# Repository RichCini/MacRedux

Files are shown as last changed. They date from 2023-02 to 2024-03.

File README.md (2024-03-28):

# MacRedux

Reimaging of the original Macintosh 128k logic board 820-0086-C. 

## Introduction
This project is a re-implementation of a Macintosh 128k logic board. From this, I hope to
derive the 128k/512k hybrid board. Primarily, I expect these would be used to replace
an original logic board that has been damaged. There are several components that are generally 
"unobtanium" without harvesting from another board. These parts include the six PLDs (of which 
only 2 or 3 may have been decoded per some Google searching), the IWM (disk drive controller), 
the RTC chip (although a clone seems to have been made by someone), three RC dampers, and the 
external floppy connector (a custom 19-pin connector that looks like it used the DB13W3 shell
size). The DB19F was also used on the //gs, Amiga, and NeXT machines, among others. You can 
still occasionally find them on eBay. I purchased 2 just to have them for measurements.

## Project Status
The board has been fully test plotted but has not been sent to manufacturing. I was able to
purchase an original board, so most of the critical measurements have been validated. However,
there still may be minor differences between the original and this version, mostly relating to
the rear connectors, the RJ11 jack, and the pushbutton switches on the side. 

## Versions
* v1.0-001: Initial prototype based on original schematic.

## Known Bugs/Issues
* The board still contains several DRC errors, mostly due to components encroaching on
eachother ("porch violations"). There will likely be permanent encroachments given how
dense the board is in certain areas.

* Certain components (like the push buttons, keyboard connector, and audio jack) 
are being replaced with what I think are current equivalents, so further adjustments could
be needed for those so that they are positioned properly on the planar.

* As of now, the PALs have not been fully decoded. The archive includes a text
file with some notes I've collected on the topic from various places on the Net.

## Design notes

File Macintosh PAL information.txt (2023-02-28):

See actual Web file archive at
https://web.archive.org/web/20020226105207/http://www.mactech.com/articles/mactech/Vol.01/01.11/PAL/index.html)
With added information from http://retro.co.za/ccc/mac/ReverseEngineering/PALs.html

PROGRAMMABLE LOGIC IN THE MACINTOSH

512K MAC:
 
ASG  16R6 Disk speed control, sound generator.
BMU0 16R4 Ram control (read, write, DTACK)
BMU1 16L8 Address decoding
LAG  16R8 Video generator
TSG  16R6 Divide by 2, divide by 4.25.
TSM  16R4 Generates RAS and CAS for DRAM

The Macintosh uses six HAL devices, of four different types. These types are 
16L8, 16R8, 16R6, and 16R4.

The 16L8 is very similar to the example I've given, with 8 dedicated input pins, 
and 8 pins which are programmable as inputs or outputs. The part number, 16L8, 
means there are 16 possible inputs, 8 possible outputs, and the outputs are active 
low. The active low outputs can be programmed as active high using DeMorgan's Law, 
as I described above.

The 16R8 is identical to the 16L8, only there is a D-type flip-flop (register) 
at the output of each OR term. Figure 10 shows the structure of one registered 
output term. The 16R6 and 16R4 have 6 and 4 output registers respectively, with 
the remaining 2 and 4 terms direct combinatorial outputs like the 16L8.

MACINTOSH HAL FUNCTIONS

A look at the functions that the Mac's HALs perform give a good feel for the type of 
applications where programmable logic is used. There are many instances of simple 
random-logic replacement, but there are also some clever applications that demonstrate 
the versatility of these devices.

The 6 HALs in the Mac have designators silk-screened on the PC board next to them. 
I'll refer to them by those names, although I can't figure out what they stand for.

BMU1

BMU1 is a 16L8 device which performs the major address decoding functions. It has 
as inputs the higher order address lines A21, A22, and A23 from the processor, along 
with the overlay bit (for a description of the overlay bit, see the August issue). 
These bits are decoded to generate enable signals for the RAM, ROM, the IWM (disk 
controller) and the SCC serial chip.

/AS 	 I 	11	 10		GND
/IWM 	 O 	12	 9	 I 	A21
/SCCRD	 O 	13	 8	 I 	A22
/SCCEN	 O 	14	 7	 I 	A23
/VPA 	 O 	15	 6	 I 	OVERLAY
/ROM 	 O 	16	 5	 I 	L13
/RAM 	 O 	17	 4	 I 	/VCA
VC0 	 O 	18	 3	 I 	VA6
VC1 	 O 	19	 2	 I 	VA7
Vcc 		20	 1	 I 	VA8

/IWM   :=  A23 *  A22 * /A21 * /AS             ; 0xC0 0000 - 0xDF FFFF (0xDF E1FF)
/SCCRD :=  A23 * /A22 * /A21 * /AS             ; 0x80 0000 - 0x9F FFFF (0x9F FFF8)
/SCCEN :=  A23 * /A22 * /AS                    ; 0x80 0000 - 0xBF FFFF (0x9F FFF8 - RD, 0xBF FFF9 - WR)
/VPA   :=  A23 *  A22 *  A21 * /AS             ; Synchronous I/O (6800 style) 0xE0 0000 - 0xFF FFFF
/ROM   := /A23 *  A22 * /A21 * /AS             ; 0x40 0000 - 0x5F FFFF
        + /A23 * /A22 * /A21 * /AS * OVERLAY   ; 0x00 0000 - 0x1F FFFF when OVERLAY enabled
        +  A23 * /A22 * /AS                    ; 0x80 0000 - 0xBF FFFF
        +  A23 * /A21 * /AS                    ; 0x80 0000 - 0x9F FFFF and 0xC0 0000 - 0xDF FFFF
/RAM   := /A23 * /A22 * /A21 * /AS * /OVERLAY  ; 0x00 0000 - 0x1F FFFF
        + /A23 *  A22 *  A21 * /AS * OVERLAY   ; 0x60 0000 - 0x7F FFFF when OVERLAY is enabled
VC0    :=
VC1    :=

Minimized Product of Sums:
/IWM = (/AS+A21+A22'+A23');
/SCCRD = (/AS+A21+A22+A23');
/SCCEB = (/AS+A22+A23');
/VPA = (/AS+A21'+A22'+A23');
/ROM = (A22+A23')(A21+A22')(A22+OVERLAY')(A22'+A23+OVERLAY);
/RAM = (A22+A23')(A22+OVERLAY)(A21'+A22'+A23+OVERLAY');
VC0 = (L13'+/VCA+VA6')(L13+/VCA+VA7'+VA8);
VC1 = (L13'+/VCA+VA6')(L13+/VCA+VA7+VA8');

LAG

LAG is a 16R8 device which performs the majority of the video control functions. It 
has as inputs most of the video address counter outputs, which are decoded to create 
output signals which load the video shift register, provide the CRT sweep circuitry 
with horizontal and vertical syncs, increment and reset the video address counters, 
and switch the RAM address multilplexers between CPU, video, and sound addresses.

/TSEN1 	/OE 	11	10		GND
/LDPS 	 R 	12	9	 I 	VA0
/VSYNC	 R 	13	8	 I 	VA1
/HSYNC	 R 	14	7	 I 	VA2
VID/u*	 R 	15	6	 I 	TC
H4 	 R 	16	5	 I 	C1M
/DMA 	 R 	17	4	 I 	VA3
RESLYN	 R 	18	3	 I 	VC1
RESNYB	 R 	19	2	 I 	VC0
Vcc 		20	1	CLK 	C16M

A 16R8 has eight (+ a clock) inputs and eight outputs.
Clock: C16M
Inputs: VC0, VC1, VA0, VA1, VA2, VA3, TC, C1M
Outputs: /LDPS, /VSYNC, /HSYNC, VID/u*, H4, /DMA, RESLYN, RESNYB

BMU0

BMU0 is a 16R4 device which generates RAM read and write signals from the RAM enable 
output of BMU1 and the processor R/W line. It is also used as a counter to create 
two video address lines (VA12 and VA13) because the video counter is only 12 bits 
wide (VA0-VA11). In addition, it also generates DTACK, the data transfer acknowledge 
handshake signal to the processor, and synchronizes the output of the video shift 
register with the master oscillator. This is a very good example of the many 
different types of functions that can be handled with a single programmable device.

/TSEN0	/CS 	11	10		GND
/RAM_RD	 O 	12	9	 I 	R/W
/RAM_RW	 O 	13	8	 I 	L13
VA12 	 R 	14	7	 I 	L12
/VCA	 R 	15	6	 I 	VA11
/VIDOUT	 R 	16	5	 I 	VA10
VA13 	 R 	17	4	 I 	VA9
SERVID 	 O 	18	3	 I 	/ROM
/DTACK	 O 	19	2	 I 	/RAM
Vcc 		20	1	CLK 	C16M

SERVID from the dual LS166 video shifters and VIDOUT to the monitor. 

TSM

TSM is a 16R4 device whose major function is control of the dynamic RAM. For inputs, 
it has the decoded RAM enable signal, along with the address and data strobes from 
the processor which signify whether the data transfer will be low byte, hi byte, 
or word. From these the RAS and CAS strobes are generated, and the row/column address 
multiplexer is controlled. Until there were PALs, this type of dynamic RAM control 
function required either about 10-20 discrete TTL packages, or a 40 pin LSI dynamic 
RAM controller which usually didn't do what you wanted anyway.

/TSEN0	/CS 	11	10		GND
/CAS0 	 O 	12	9	 I 	/LDS
/CAS1 	 O 	13	8	 I 	/UDS
/RAS 	 R 	14	7	 I 	/AS
TC 	 R 	15	6	 I 	/ROM
C1M 	 R 	16	5	 I 	/RAM
C4M 	 R 	17	4	 I 	VID/u*
C2M 	 O 	18	3	 I 	C8M
/DTACK	 O 	19	2	 I 	C16M
Vcc 		20	1	CLK 	C16M

PAL16R8	 PAL DESIGN SPECIFICATIONS

16MBUF C16M 8M MU RAMEN ROMEN AS UDS LDS GND 
TSEN CAS0 CAS1 RAS TC 1M 4M 2M DTACK VCC

RAS is the DRAM Row Address Strobe.

RAS: =       /4M *             /RAS
     +  8M *  4M *             /RAS + 
     + /8M *  4M *       /2M * /RAS
     +  8M * /4M *  1M *        RAS
     +  8M * /4M * /1M *  2M *  RAS
     + /8M *  4M * /1M *        RAS *  LDS
     + /8M *  4M * /1M *        RAS *  UDS
     + /8M *  4M * /1M *        RAS * /LDS * /UDS * /CAS0
     + 

TC goes to the LAG and to the video counter (U1F)

TC:= 8M + /4M + 2M +  /1M + RAS

1M: =      /8M *  4M * /2M * 1M * /RAS + 
     /1M *  8M * /4M * /RAS + 
     /1M * /8M *  4M * 2M * /RAS + 
     /1M *              RAS + 
     /1M * /8M * /4M * /RAS + 
     /1M * 8M *   4M * /RAS

4M: =                    1M *  RAS + 
       8M *  4M *  2M * /1M *  RAS + 
      /8M * /4M *       /1M *  RAS + 
       8M * /4M *  2M * /1M *  RAS + 
      /8M *  4M * /2M *       /RAS + 
there may be a line missing here..... 

2M: = /C16M *       /8M * /4M * /RAS
    +         /2M + /8M + /4M 
    +         /2M + /1M + * /TC
    +  C16M * /2M
    + /C16M * /8M * /4M * /1M * RAS * /ROMEN * /RAMEN * /AS
    + /2M * 4M
    + /2M * 8M * /4M *1M * MU

DTACK := /C16M * /8M * /4M *        /RAS * /AS * /ROMEN *  RAMEN
      +  /C16M * /8M * /4M * /1M  * /RAS * /AS * /RAMEN *  ROMEN
      +  /C16M * /8M * /4M *  1M  * /RAS * /AS * /RAMEN *  ROMEN * /MU
      +  /C16M * /8M *  4M * /1M  *  RAS * /AS * /RAMEN * /ROMEN
      +  /DTACK * /UDS
      +  /DATACK * /LDS
      +  /DATACK * /RAS

This is probably not right for the Mac Plus...

CAS0: =  4M * /2M * /RAS * /DTACK * /RAMEN * ROMEN * /LDS * MU
      +  4M * /2M * 1M * /RAS * MU
      + /CAS0 
      + /RAS
      +  8M + 4M + /2M * /1M * RAS * /DTACK
      + /CAS0 * /2M + /1M

CAS1: = 4M * /2M * /RAS * /DTACK * /RAMEN * ROMEN * /UDS * MU
      + 4M * /2M * 1M * /RAS * MU
      + /CAS1 + /RAS 

ASG

ASG is a 16R6 device which illustrates why PALs can be so valuable. It's primary 
purpose is to take the 6-bit disk speed value which is fetched at the end of every
horizontal retrace period and convert it to a pulse-width modulated signal. Basically, 
it's a 6-bit counter. This leaves a couple of inputs and an output available, which 
are used to control the loading of the sound generator pulse-width modulator, which 
is a counter made up of TTL devices. If a discrete counter had been used for the 
disk PWM, another chip would have been required for the sound PWM load function. 
Using a PAL for a simple counter function in this instance saved a chip in the design.

As usual, Burrell's new design was very clever. The Macintosh was already continuously 
fetching data from memory to drive the video display, interleaving memory bandwidth 
between the display and processor in a similar fashion to the Apple II. But every 
44 microseconds, there was a "horizontal blanking interval" where no video data was 
needed, so Burrell used that time to fetch data for the sound. That gave us a sample 
rate of 22kHz, which would allow us to do frequencies up to 11kHz, which isn't too bad. 

/TSEN2	/OE 	11	 10		GND
/DMALD	 O 	12	 9	 I 	TC
PWM 	 R 	13	 8	 I 	/DMA
N/C 	 R 	14	 7	 I 	RDQ5
N/C 	 R 	15	 6	 I 	RDQ4
N/C 	 R 	16	 5	 I 	RDQ3
N/C 	 R 	17	 4	 I 	RDQ2
N/C 	 R 	18	 3	 I 	RDQ1
N/C 	 O 	19	 2	 I 	RDQ0
Vcc 		20	 1	CLK 	C16MF

TSG

This one is my favorite. The TSG is a 16R6 device which illustrates the power of 
programmable logic. It serves a couple of mundane functions concerning interrupts 
and the keyboard clock, but by far it's most interesting job is as a clock generator 
for the SCC serial chip.

The master oscillator frequency in the Macintosh is 15.667 MHz. This is divided by 2 
in the TSG to get the 7.834 MHz processor clock. In order for the SCC to be able to 
operate at a baud rate of 230.4 KBaud, which is what AppleTalk requires, it needs an 
input clock frequency of 3.686 MHz.

If you pull down your calculator desk accessory, you'll find that 15.667 ÷ 3.686 = 4.25. 
This means that the TSG needs to divide the 15.667 MHz master oscillator by 4.25 in 
order to get a 3.686 MHz clock. How is this done, since 4.25 is not even an integer, 
let alone a binary number?

Let's call the 15.667 MHz clock the MO_clk and the 3.686 MHz clock the SCC_clk. For 
every 17 MO_clk periods there are 4 SCC_clk periods (17 ÷ 4 = 4.25). The way the TSG 
generates the SCC_clk is count to 4 three times and then count to 5 once 
(4 + 4 + 4 + 5 = 17). See Figure 11 for a graphical description. Try that using a 
single TTL counter chip!

TSEN2 	/OE 	11	 10		GND
D0 	 O 	12	 9	 I 	/VIAIRQ
N/C 	 R 	13	 8	 I 	/IPL1
C3.7MF 	 R 	14	 7	 I 	KBD.ACLK
N/C 	 R 	15	 6	 I 	Eu
N/C 	 R 	16	 5	 I 	4M
KBD.SCLK R 	17	 4	 I 	TC
C8M 	 R 	18	 3	 I 	A19
/IPL0 	 O 	19	 2	 I 	/VPA
Vcc 		20	 1	CLK 	C16M

C8M :=

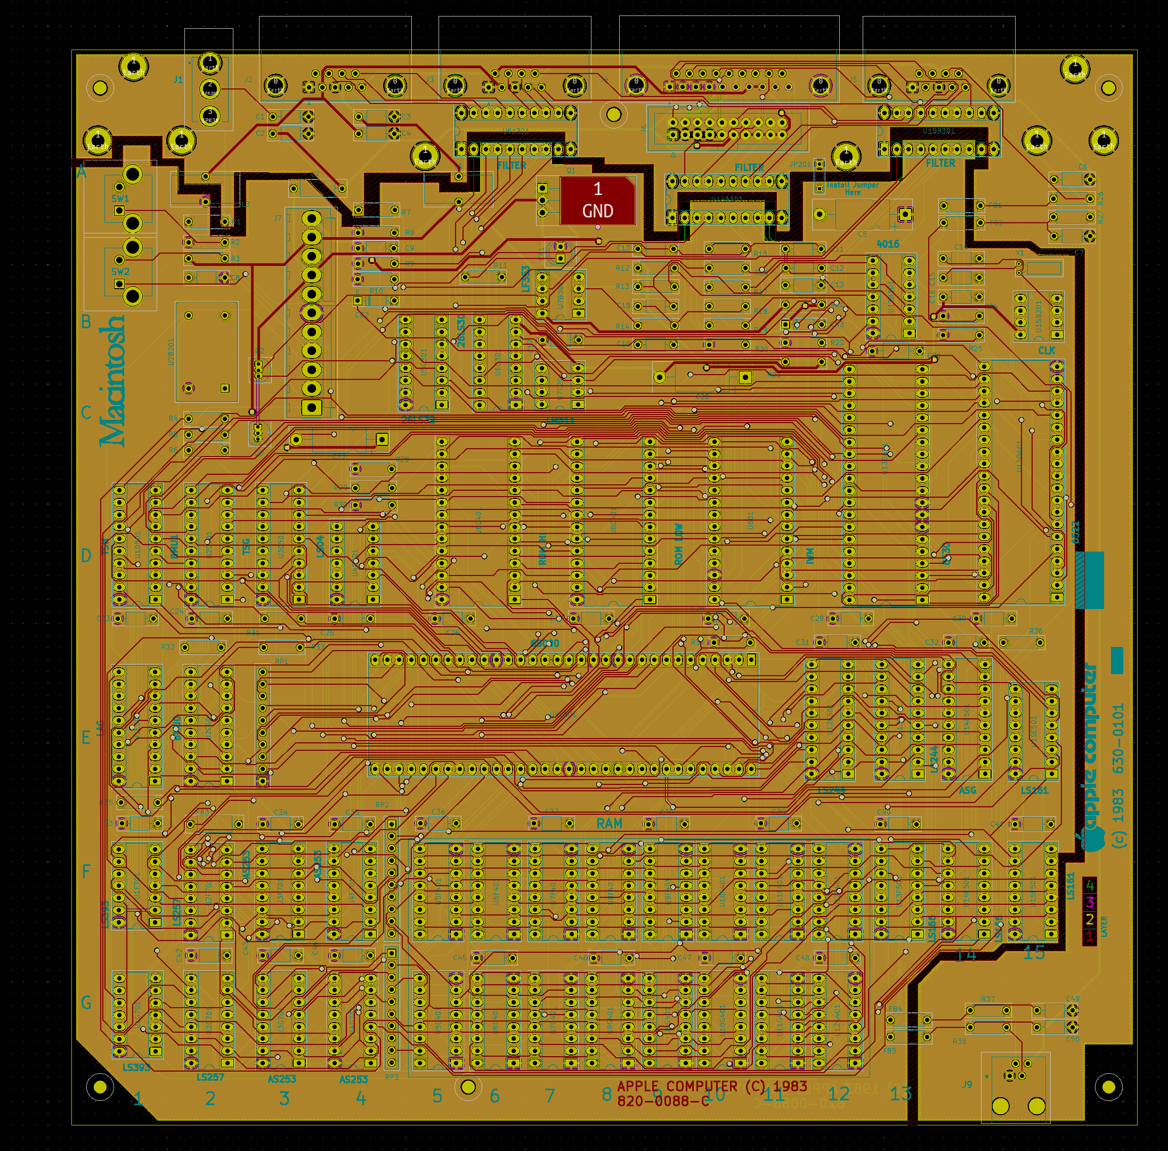
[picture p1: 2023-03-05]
Screen Shot 2023-02-06 at 2.04.48 PM.png

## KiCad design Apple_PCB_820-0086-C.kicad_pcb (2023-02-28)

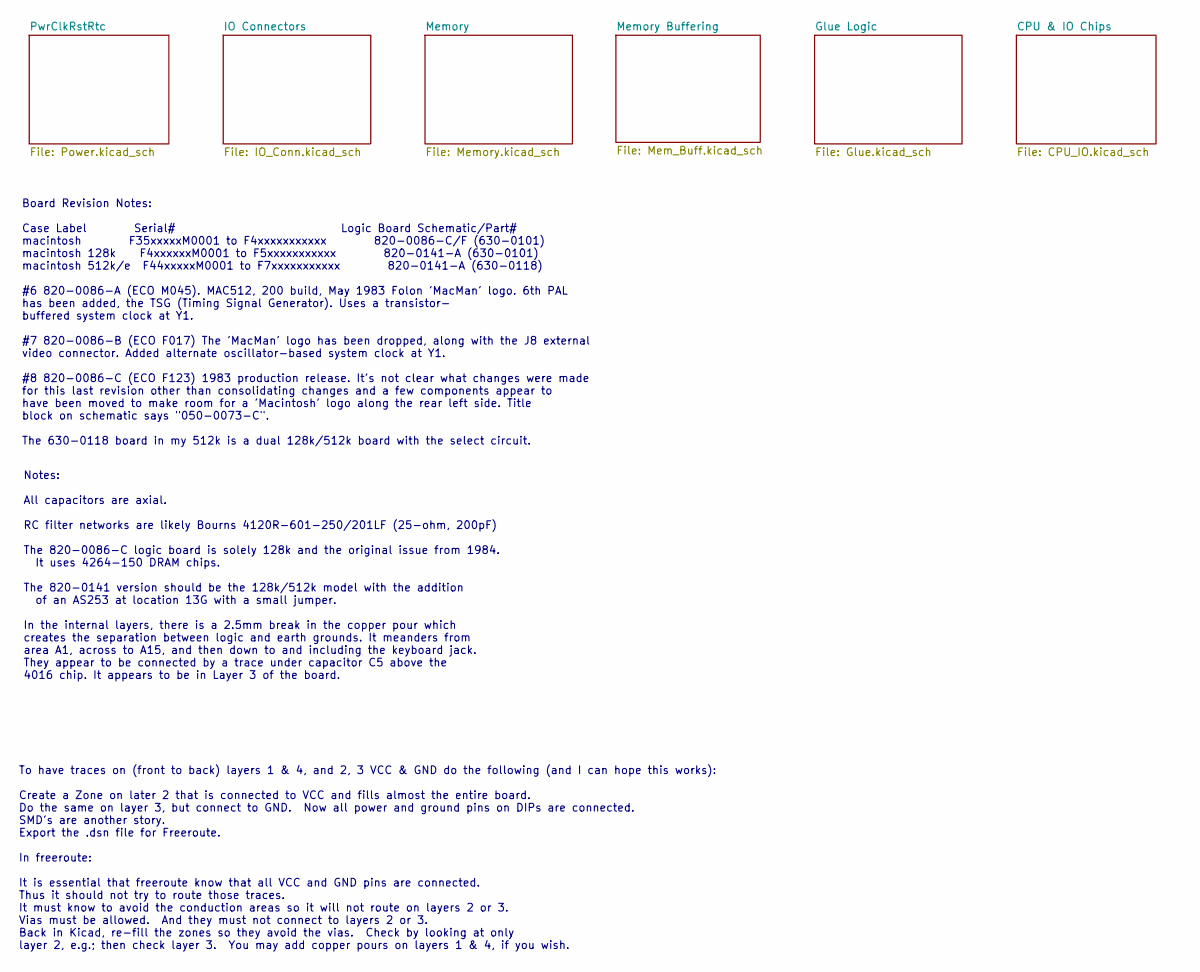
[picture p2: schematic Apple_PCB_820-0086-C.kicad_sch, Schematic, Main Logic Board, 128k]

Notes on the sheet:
Board Revision Notes: Case Label Serial# Logic Board Schematic/Part# macintosh F35xxxxxM0001 to F4xxxxxxxxxxx 820-0086-C/F (630-0101) macintosh 128k F4xxxxxxM0001 to F5xxxxxxxxxxx 820-0141-A (630-0101) macintosh 512k/e F44xxxxxM0001 to F7xxxxxxxxxxx 820-0141-A (630-0118) #6 820-0086-A (ECO M045). M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
To have traces on (front to back) layers 1 & 4, and 2, 3 VCC & GND do the following (and I can hope this works): Create a Zone on later 2 that is connected to VCC and fills almost the entire board. Do the same on layer 3, but connect to GND. Now all power and ground pins on DIPs are connected. SMD'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
Notes: All capacitors are axial. RC filter networks are likely Bourns 4120R-601-250/201LF (25-ohm, 200pF) The 820-0086-C logic board is solely 128k and the original issue from 1984. It uses 4264-150 DRAM chips. The 820-0141 version should be the 128k/512k model with the addition of an AS253 at loca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

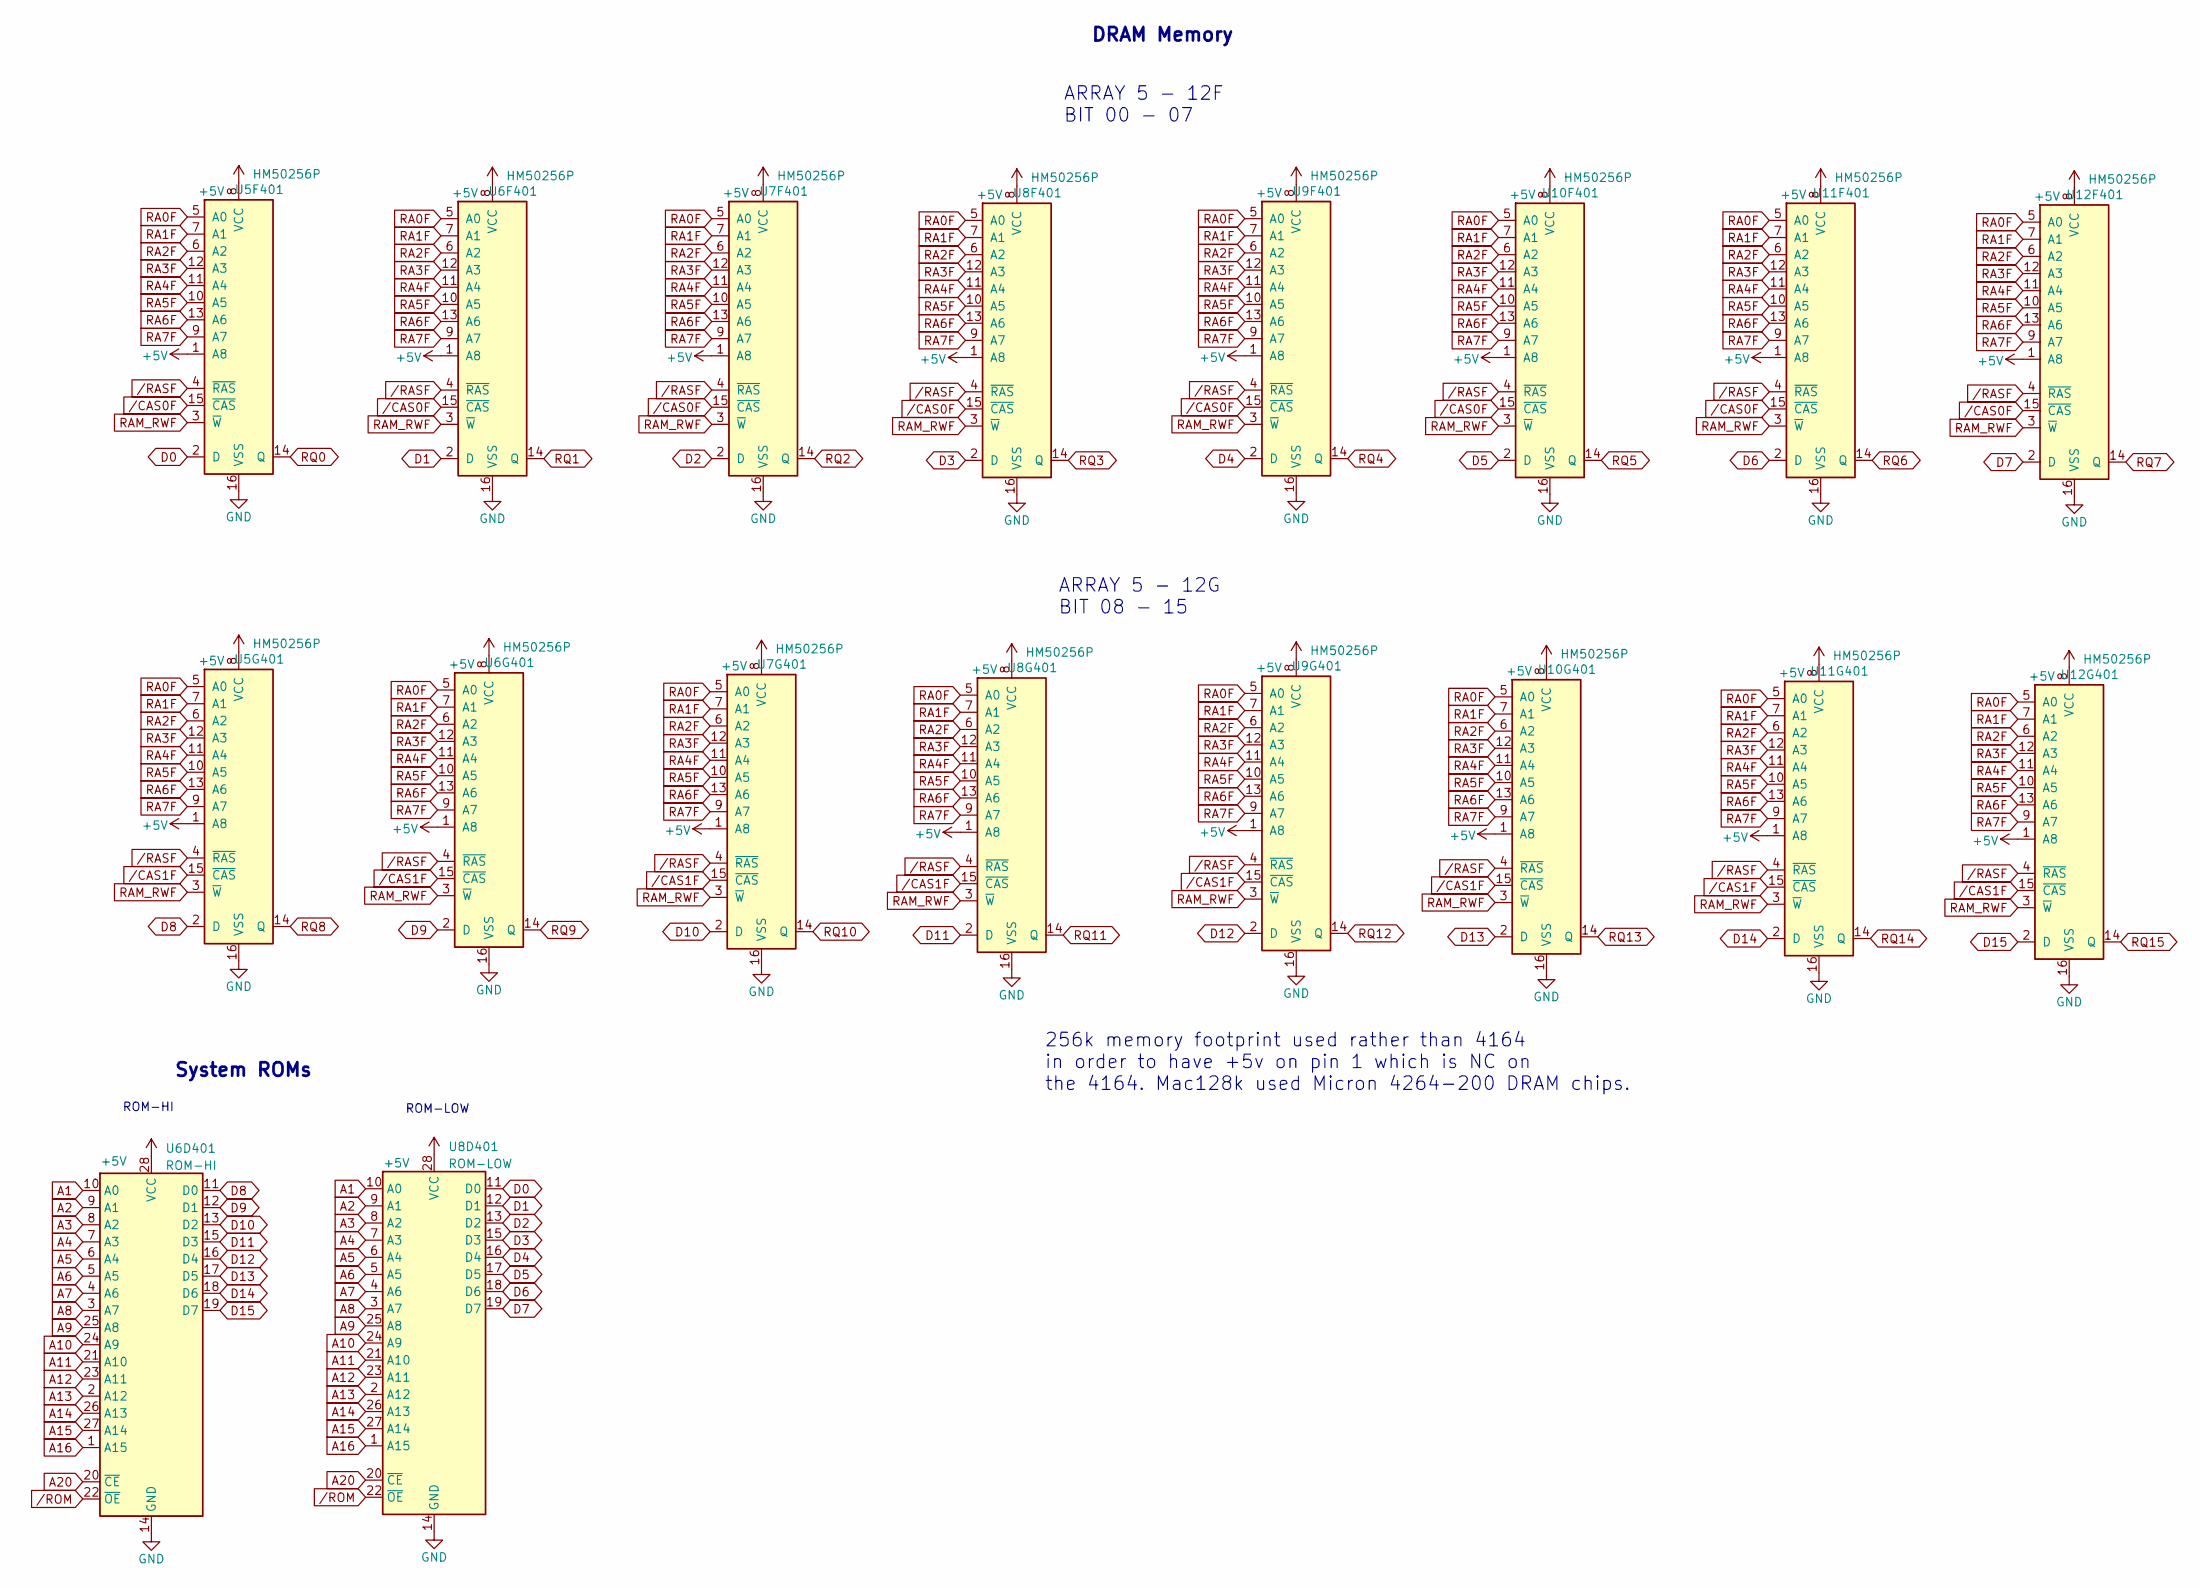
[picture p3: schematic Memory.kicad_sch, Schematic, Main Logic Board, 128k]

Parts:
U5F401, U5G401, U6F401, U6G401, U7F401, U7G401, U8F401, U8G401, U9F401, U9G401, U10F401, U10G401, U11F401, U11G401, U12F401, U12G401: HM50256P; DIP-16_W7.62mm_Socket_LongPads
U6D401: ROM-HI; DIP-28_W15.24mm_LongPads
U8D401: ROM-LOW; DIP-28_W15.24mm_LongPads

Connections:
+5V: U5F401.1 (A8), U5F401.8 (VCC), U5G401.1 (A8), U5G401.8 (VCC), U6D401.28 (VCC), U6F401.1 (A8), U6F401.8 (VCC), U6G401.1 (A8), U6G401.8 (VCC), U7F401.1 (A8), U7F401.8 (VCC), U7G401.1 (A8), U7G401.8 (VCC), U8D401.28 (VCC), U8F401.1 (A8), U8F401.8 (VCC), U8G401.1 (A8), U8G401.8 (VCC), U9F401.1 (A8), U9F401.8 (VCC), U9G401.1 (A8), U9G401.8 (VCC), U10F401.1 (A8), U10F401.8 (VCC), U10G401.1 (A8), U10G401.8 (VCC), U11F401.1 (A8), U11F401.8 (VCC), U11G401.1 (A8), U11G401.8 (VCC), U12F401.1 (A8), U12F401.8 (VCC), U12G401.1 (A8), U12G401.8 (VCC); also elsewhere on the board
A1: U6D401.10 (A0), U8D401.10 (A0); also elsewhere on the board
A2: U6D401.9 (A1), U8D401.9 (A1); also elsewhere on the board
A3: U6D401.8 (A2), U8D401.8 (A2); also elsewhere on the board
A4: U6D401.7 (A3), U8D401.7 (A3); also elsewhere on the board
A5: U6D401.6 (A4), U8D401.6 (A4); also elsewhere on the board
A6: U6D401.5 (A5), U8D401.5 (A5); also elsewhere on the board
A7: U6D401.4 (A6), U8D401.4 (A6); also elsewhere on the board
A8: U6D401.3 (A7), U8D401.3 (A7); also elsewhere on the board
A9: U6D401.25 (A8), U8D401.25 (A8); also elsewhere on the board
A10: U6D401.24 (A9), U8D401.24 (A9); also elsewhere on the board
A11: U6D401.21 (A10), U8D401.21 (A10); also elsewhere on the board
A12: U6D401.23 (A11), U8D401.23 (A11); also elsewhere on the board
A13: U6D401.2 (A12), U8D401.2 (A12); also elsewhere on the board
A14: U6D401.26 (A13), U8D401.26 (A13); also elsewhere on the board
A15: U6D401.27 (A14), U8D401.27 (A14); also elsewhere on the board
A16: U6D401.1 (A15), U8D401.1 (A15); also elsewhere on the board
A20: U6D401.20 (~CE), U8D401.20 (~CE); also elsewhere on the board
D0: U5F401.2 (D), U8D401.11 (D0); also elsewhere on the board
D1: U6F401.2 (D), U8D401.12 (D1); also elsewhere on the board
D2: U7F401.2 (D), U8D401.13 (D2); also elsewhere on the board
D3: U8D401.15 (D3), U8F401.2 (D); also elsewhere on the board
D4: U8D401.16 (D4), U9F401.2 (D); also elsewhere on the board
D5: U8D401.17 (D5), U10F401.2 (D); also elsewhere on the board
D6: U8D401.18 (D6), U11F401.2 (D); also elsewhere on the board
D7: U8D401.19 (D7), U12F401.2 (D); also elsewhere on the board
D8: U5G401.2 (D), U6D401.11 (D0); also elsewhere on the board
D9: U6D401.12 (D1), U6G401.2 (D); also elsewhere on the board
D10: U6D401.13 (D2), U7G401.2 (D); also elsewhere on the board
D11: U6D401.15 (D3), U8G401.2 (D); also elsewhere on the board
D12: U6D401.16 (D4), U9G401.2 (D); also elsewhere on the board
D13: U6D401.17 (D5), U10G401.2 (D); also elsewhere on the board
D14: U6D401.18 (D6), U11G401.2 (D); also elsewhere on the board
D15: U6D401.19 (D7), U12G401.2 (D); also elsewhere on the board
GND: U5F401.16 (VSS), U5G401.16 (VSS), U6D401.14 (GND), U6F401.16 (VSS), U6G401.16 (VSS), U7F401.16 (VSS), U7G401.16 (VSS), U8D401.14 (GND), U8F401.16 (VSS), U8G401.16 (VSS), U9F401.16 (VSS), U9G401.16 (VSS), U10F401.16 (VSS), U10G401.16 (VSS), U11F401.16 (VSS), U11G401.16 (VSS), U12F401.16 (VSS), U12G401.16 (VSS); also elsewhere on the board
RA0F: U5F401.5 (A0), U5G401.5 (A0), U6F401.5 (A0), U6G401.5 (A0), U7F401.5 (A0), U7G401.5 (A0), U8F401.5 (A0), U8G401.5 (A0), U9F401.5 (A0), U9G401.5 (A0), U10F401.5 (A0), U10G401.5 (A0), U11F401.5 (A0), U11G401.5 (A0), U12F401.5 (A0), U12G401.5 (A0); also elsewhere on the board
RA1F: U5F401.7 (A1), U5G401.7 (A1), U6F401.7 (A1), U6G401.7 (A1), U7F401.7 (A1), U7G401.7 (A1), U8F401.7 (A1), U8G401.7 (A1), U9F401.7 (A1), U9G401.7 (A1), U10F401.7 (A1), U10G401.7 (A1), U11F401.7 (A1), U11G401.7 (A1), U12F401.7 (A1), U12G401.7 (A1); also elsewhere on the board
RA2F: U5F401.6 (A2), U5G401.6 (A2), U6F401.6 (A2), U6G401.6 (A2), U7F401.6 (A2), U7G401.6 (A2), U8F401.6 (A2), U8G401.6 (A2), U9F401.6 (A2), U9G401.6 (A2), U10F401.6 (A2), U10G401.6 (A2), U11F401.6 (A2), U11G401.6 (A2), U12F401.6 (A2), U12G401.6 (A2); also elsewhere on the board
RA3F: U5F401.12 (A3), U5G401.12 (A3), U6F401.12 (A3), U6G401.12 (A3), U7F401.12 (A3), U7G401.12 (A3), U8F401.12 (A3), U8G401.12 (A3), U9F401.12 (A3), U9G401.12 (A3), U10F401.12 (A3), U10G401.12 (A3), U11F401.12 (A3), U11G401.12 (A3), U12F401.12 (A3), U12G401.12 (A3); also elsewhere on the board
RA4F: U5F401.11 (A4), U5G401.11 (A4), U6F401.11 (A4), U6G401.11 (A4), U7F401.11 (A4), U7G401.11 (A4), U8F401.11 (A4), U8G401.11 (A4), U9F401.11 (A4), U9G401.11 (A4), U10F401.11 (A4), U10G401.11 (A4), U11F401.11 (A4), U11G401.11 (A4), U12F401.11 (A4), U12G401.11 (A4); also elsewhere on the board
RA5F: U5F401.10 (A5), U5G401.10 (A5), U6F401.10 (A5), U6G401.10 (A5), U7F401.10 (A5), U7G401.10 (A5), U8F401.10 (A5), U8G401.10 (A5), U9F401.10 (A5), U9G401.10 (A5), U10F401.10 (A5), U10G401.10 (A5), U11F401.10 (A5), U11G401.10 (A5), U12F401.10 (A5), U12G401.10 (A5); also elsewhere on the board
RA6F: U5F401.13 (A6), U5G401.13 (A6), U6F401.13 (A6), U6G401.13 (A6), U7F401.13 (A6), U7G401.13 (A6), U8F401.13 (A6), U8G401.13 (A6), U9F401.13 (A6), U9G401.13 (A6), U10F401.13 (A6), U10G401.13 (A6), U11F401.13 (A6), U11G401.13 (A6), U12F401.13 (A6), U12G401.13 (A6); also elsewhere on the board
RA7F: U5F401.9 (A7), U5G401.9 (A7), U6F401.9 (A7), U6G401.9 (A7), U7F401.9 (A7), U7G401.9 (A7), U8F401.9 (A7), U8G401.9 (A7), U9F401.9 (A7), U9G401.9 (A7), U10F401.9 (A7), U10G401.9 (A7), U11F401.9 (A7), U11G401.9 (A7), U12F401.9 (A7), U12G401.9 (A7); also elsewhere on the board
RAM_RWF: U5F401.3 (~W), U5G401.3 (~W), U6F401.3 (~W), U6G401.3 (~W), U7F401.3 (~W), U7G401.3 (~W), U8F401.3 (~W), U8G401.3 (~W), U9F401.3 (~W), U9G401.3 (~W), U10F401.3 (~W), U10G401.3 (~W), U11F401.3 (~W), U11G401.3 (~W), U12F401.3 (~W), U12G401.3 (~W); also elsewhere on the board
RQ0: U5F401.14 (Q); also elsewhere on the board
RQ1: U6F401.14 (Q); also elsewhere on the board
RQ2: U7F401.14 (Q); also elsewhere on the board
RQ3: U8F401.14 (Q); also elsewhere on the board
RQ4: U9F401.14 (Q); also elsewhere on the board
RQ5: U10F401.14 (Q); also elsewhere on the board
RQ6: U11F401.14 (Q); also elsewhere on the board
RQ7: U12F401.14 (Q); also elsewhere on the board
RQ8: U5G401.14 (Q); also elsewhere on the board
RQ9: U6G401.14 (Q); also elsewhere on the board
RQ10: U7G401.14 (Q); also elsewhere on the board
RQ11: U8G401.14 (Q); also elsewhere on the board
RQ12: U9G401.14 (Q); also elsewhere on the board
RQ13: U10G401.14 (Q); also elsewhere on the board
RQ14: U11G401.14 (Q); also elsewhere on the board
RQ15: U12G401.14 (Q); also elsewhere on the board
/CAS0F: U5F401.15 (~CAS), U6F401.15 (~CAS), U7F401.15 (~CAS), U8F401.15 (~CAS), U9F401.15 (~CAS), U10F401.15 (~CAS), U11F401.15 (~CAS), U12F401.15 (~CAS); also elsewhere on the board
/CAS1F: U5G401.15 (~CAS), U6G401.15 (~CAS), U7G401.15 (~CAS), U8G401.15 (~CAS), U9G401.15 (~CAS), U10G401.15 (~CAS), U11G401.15 (~CAS), U12G401.15 (~CAS); also elsewhere on the board
/RASF: U5F401.4 (~RAS), U5G401.4 (~RAS), U6F401.4 (~RAS), U6G401.4 (~RAS), U7F401.4 (~RAS), U7G401.4 (~RAS), U8F401.4 (~RAS), U8G401.4 (~RAS), U9F401.4 (~RAS), U9G401.4 (~RAS), U10F401.4 (~RAS), U10G401.4 (~RAS), U11F401.4 (~RAS), U11G401.4 (~RAS), U12F401.4 (~RAS), U12G401.4 (~RAS); also elsewhere on the board
/ROM: U6D401.22 (~OE), U8D401.22 (~OE); also elsewhere on the board

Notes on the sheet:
ARRAY 5 - 12F BIT 00 - 07
ROM-LOW
DRAM Memory
System ROMs
ARRAY 5 - 12G BIT 08 - 15
ROM-HI
256k memory footprint used rather than 4164 in order to have +5v on pin 1 which is NC on the 4164. Mac128k used Micron 4264-200 DRAM chips.

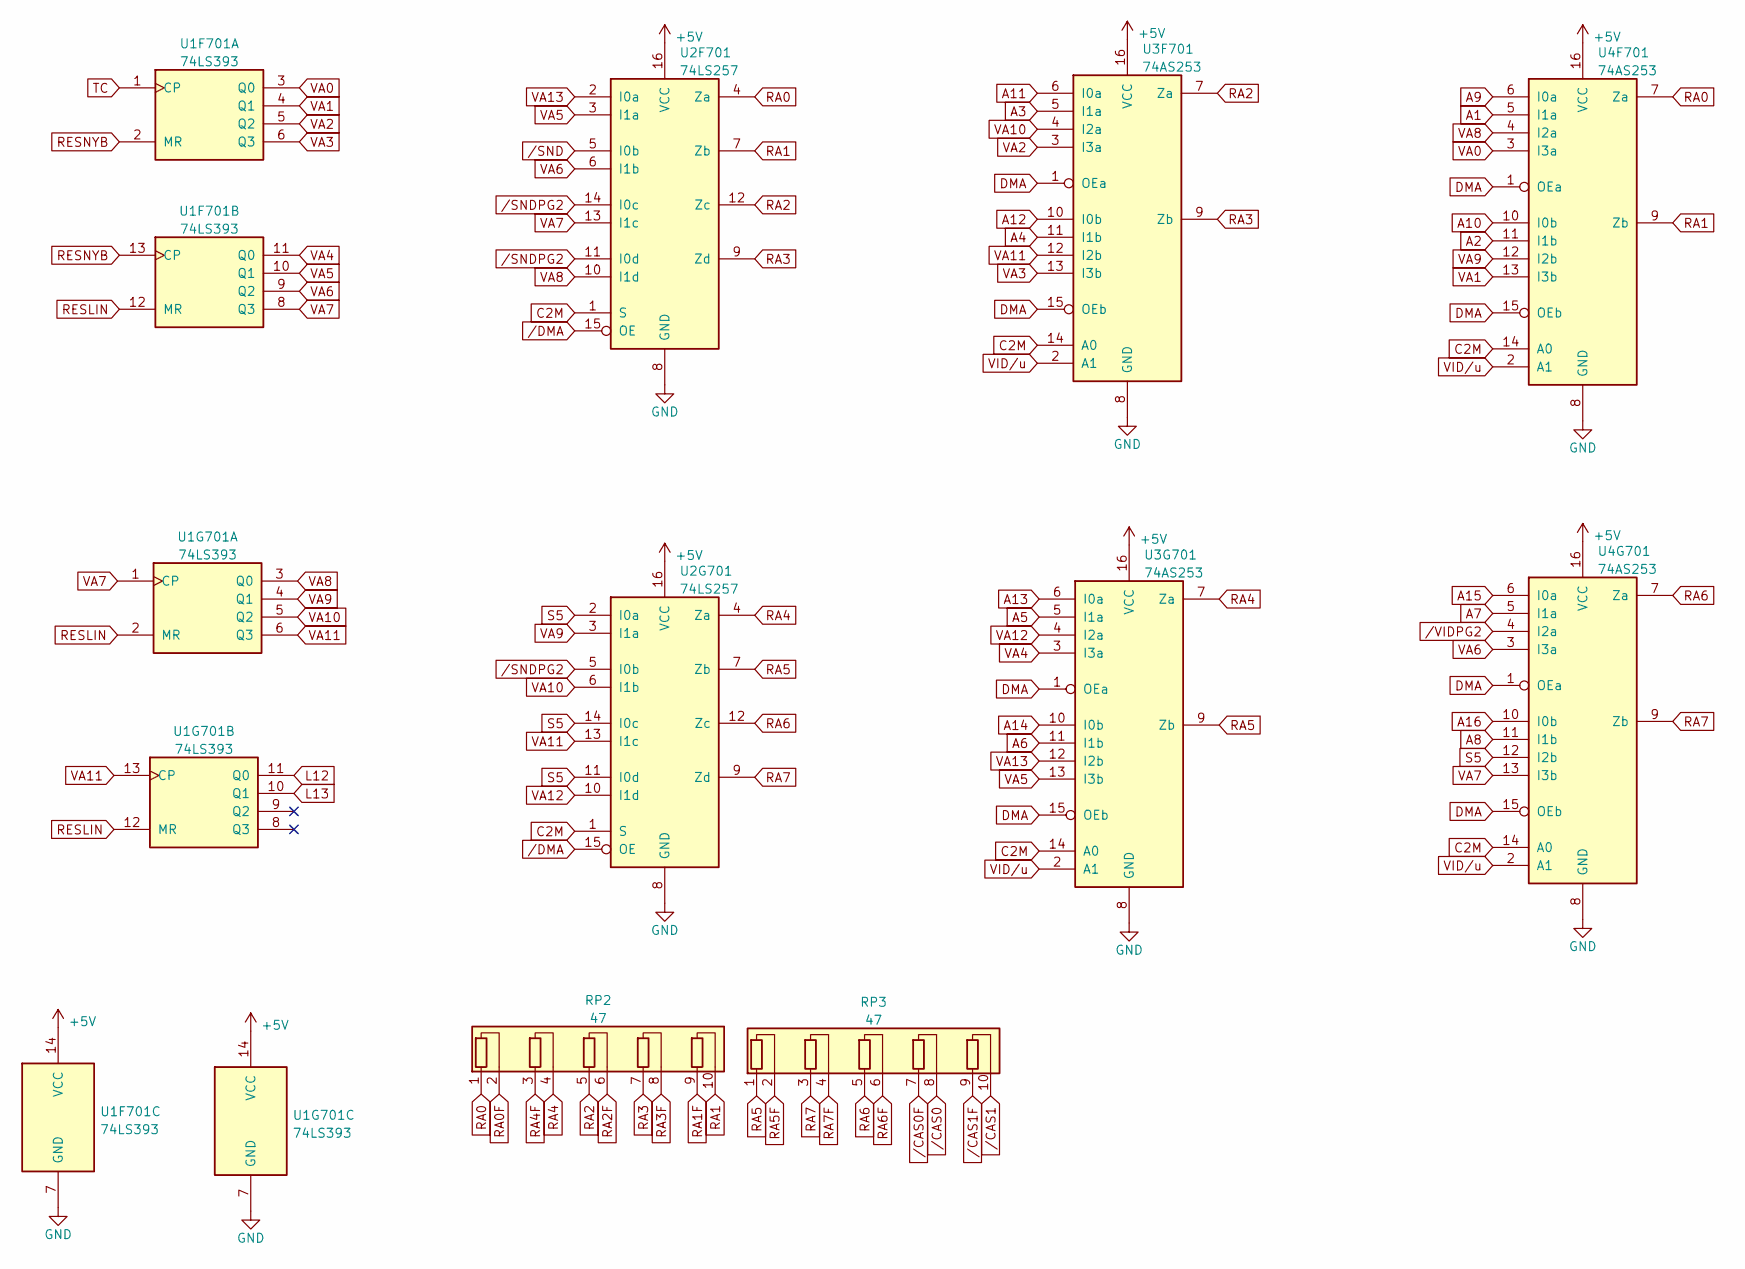
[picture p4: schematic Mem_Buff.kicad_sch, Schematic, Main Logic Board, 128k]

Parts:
RP2, RP3: 47; R_Array_SIP10
U1F701, U1G701: 74LS393; DIP-14_W7.62mm_Socket_LongPads
U2F701, U2G701: 74LS257; DIP-16_W7.62mm_Socket_LongPads
U3F701, U3G701, U4F701, U4G701: 74AS253; DIP-16_W7.62mm_Socket_LongPads

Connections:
+5V: U1F701.14 (VCC), U1G701.14 (VCC), U2F701.16 (VCC), U2G701.16 (VCC), U3F701.16 (VCC), U3G701.16 (VCC), U4F701.16 (VCC), U4G701.16 (VCC); also elsewhere on the board
A1: U4F701.5 (I1a); also elsewhere on the board
A2: U4F701.11 (I1b); also elsewhere on the board
A3: U3F701.5 (I1a); also elsewhere on the board
A4: U3F701.11 (I1b); also elsewhere on the board
A5: U3G701.5 (I1a); also elsewhere on the board
A6: U3G701.11 (I1b); also elsewhere on the board
A7: U4G701.5 (I1a); also elsewhere on the board
A8: U4G701.11 (I1b); also elsewhere on the board
A9: U4F701.6 (I0a); also elsewhere on the board
A10: U4F701.10 (I0b); also elsewhere on the board
A11: U3F701.6 (I0a); also elsewhere on the board
A12: U3F701.10 (I0b); also elsewhere on the board
A13: U3G701.6 (I0a); also elsewhere on the board
A14: U3G701.10 (I0b); also elsewhere on the board
A15: U4G701.6 (I0a); also elsewhere on the board
A16: U4G701.10 (I0b); also elsewhere on the board
C2M: U2F701.1 (S), U2G701.1 (S), U3F701.14 (A0), U3G701.14 (A0), U4F701.14 (A0), U4G701.14 (A0); also elsewhere on the board
DMA: U3F701.1 (OEa), U3F701.15 (OEb), U3G701.1 (OEa), U3G701.15 (OEb), U4F701.1 (OEa), U4F701.15 (OEb), U4G701.1 (OEa), U4G701.15 (OEb); also elsewhere on the board
GND: U1F701.7 (GND), U1G701.7 (GND), U2F701.8 (GND), U2G701.8 (GND), U3F701.8 (GND), U3G701.8 (GND), U4F701.8 (GND), U4G701.8 (GND); also elsewhere on the board
L12: U1G701.11 (Q0); also elsewhere on the board
L13: U1G701.10 (Q1); also elsewhere on the board
RA0: RP2.1 (R1.1), U2F701.4 (Za), U4F701.7 (Za)
RA0F: RP2.2 (R1.2); also elsewhere on the board
RA1: RP2.10 (R5.2), U2F701.7 (Zb), U4F701.9 (Zb)
RA1F: RP2.9 (R5.1); also elsewhere on the board
RA2: RP2.5 (R3.1), U2F701.12 (Zc), U3F701.7 (Za)
RA2F: RP2.6 (R3.2); also elsewhere on the board
RA3: RP2.7 (R4.1), U2F701.9 (Zd), U3F701.9 (Zb)
RA3F: RP2.8 (R4.2); also elsewhere on the board
RA4: RP2.4 (R2.2), U2G701.4 (Za), U3G701.7 (Za)
RA4F: RP2.3 (R2.1); also elsewhere on the board
RA5: RP3.1 (R1.1), U2G701.7 (Zb), U3G701.9 (Zb)
RA5F: RP3.2 (R1.2); also elsewhere on the board
RA6: RP3.5 (R3.1), U2G701.12 (Zc), U4G701.7 (Za)
RA6F: RP3.6 (R3.2); also elsewhere on the board
RA7: RP3.3 (R2.1), U2G701.9 (Zd), U4G701.9 (Zb)
RA7F: RP3.4 (R2.2); also elsewhere on the board
RESLIN: U1F701.12 (MR), U1G701.2 (MR), U1G701.12 (MR); also elsewhere on the board
RESNYB: U1F701.2 (MR), U1F701.13 (CP); also elsewhere on the board
S5: U2G701.2 (I0a), U2G701.11 (I0d), U2G701.14 (I0c), U4G701.12 (I2b); also elsewhere on the board
TC: U1F701.1 (CP); also elsewhere on the board
VA0: U1F701.3 (Q0), U4F701.3 (I3a); also elsewhere on the board
VA1: U1F701.4 (Q1), U4F701.13 (I3b); also elsewhere on the board
VA2: U1F701.5 (Q2), U3F701.3 (I3a); also elsewhere on the board
VA3: U1F701.6 (Q3), U3F701.13 (I3b); also elsewhere on the board
VA4: U1F701.11 (Q0), U3G701.3 (I3a)
VA5: U1F701.10 (Q1), U2F701.3 (I1a), U3G701.13 (I3b)
VA6: U1F701.9 (Q2), U2F701.6 (I1b), U4G701.3 (I3a); also elsewhere on the board
VA7: U1F701.8 (Q3), U1G701.1 (CP), U2F701.13 (I1c), U4G701.13 (I3b); also elsewhere on the board
VA8: U1G701.3 (Q0), U2F701.10 (I1d), U4F701.4 (I2a); also elsewhere on the board
VA9: U1G701.4 (Q1), U2G701.3 (I1a), U4F701.12 (I2b); also elsewhere on the board
VA10: U1G701.5 (Q2), U2G701.6 (I1b), U3F701.4 (I2a); also elsewhere on the board
VA11: U1G701.6 (Q3), U1G701.13 (CP), U2G701.13 (I1c), U3F701.12 (I2b); also elsewhere on the board
VA12: U2G701.10 (I1d), U3G701.4 (I2a); also elsewhere on the board
VA13: U2F701.2 (I0a), U3G701.12 (I2b); also elsewhere on the board
VID/u: U3F701.2 (A1), U3G701.2 (A1), U4F701.2 (A1), U4G701.2 (A1); also elsewhere on the board
/CAS0: RP3.8 (R4.2); also elsewhere on the board
/CAS0F: RP3.7 (R4.1); also elsewhere on the board
/CAS1: RP3.10 (R5.2); also elsewhere on the board
/CAS1F: RP3.9 (R5.1); also elsewhere on the board
/DMA: U2F701.15 (OE), U2G701.15 (OE); also elsewhere on the board
/SND: U2F701.5 (I0b); also elsewhere on the board
/SNDPG2: U2F701.11 (I0d), U2F701.14 (I0c), U2G701.5 (I0b); also elsewhere on the board
/VIDPG2: U4G701.4 (I2a); also elsewhere on the board

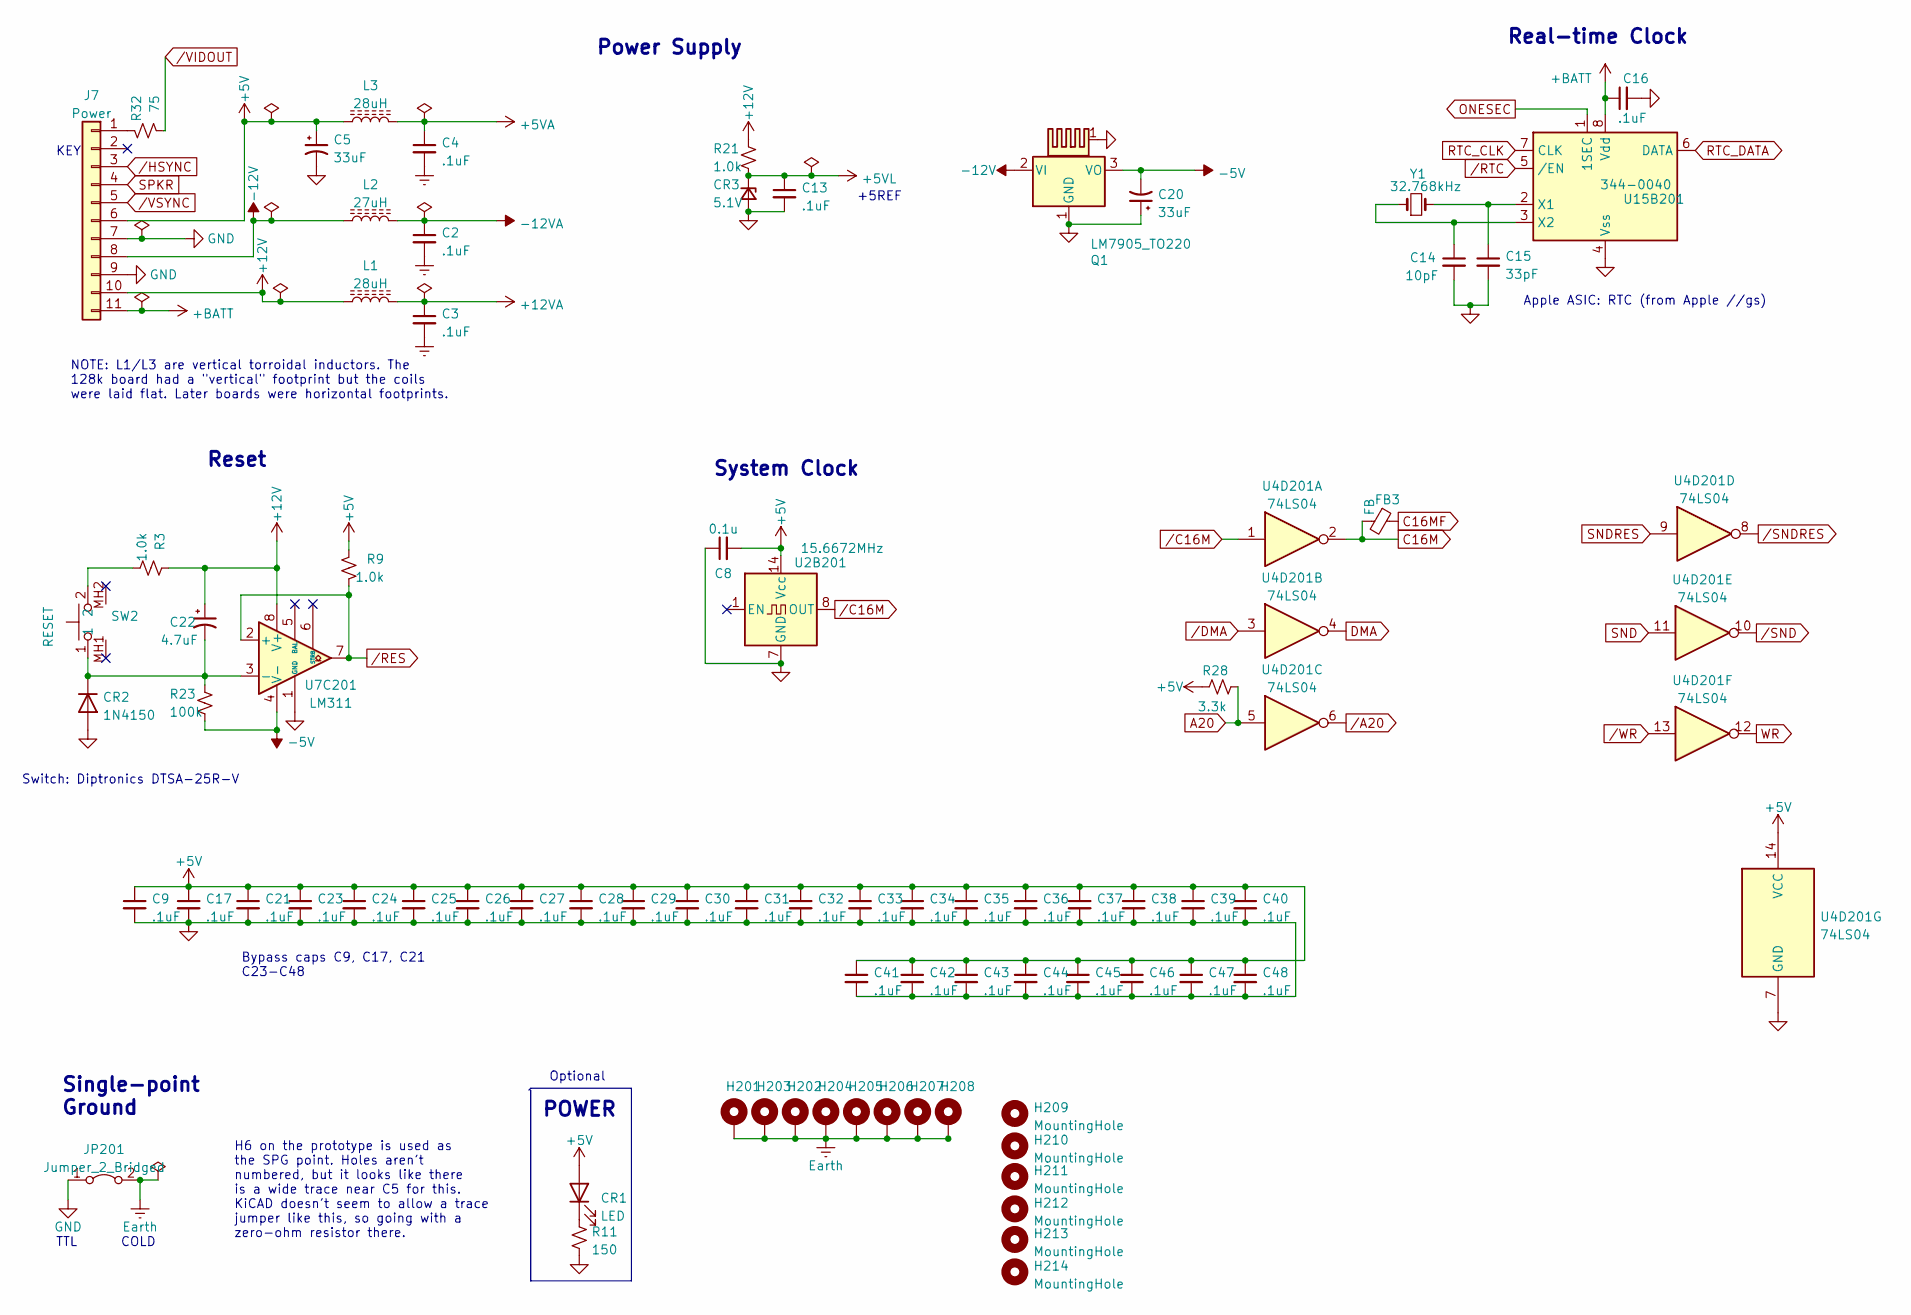
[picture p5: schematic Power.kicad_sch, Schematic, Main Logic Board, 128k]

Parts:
C2, C3, C4, C9, C13, C16, C17, C23, C24, C25, C26, C27, C28, C29, C30, C31, C32, C33, C34, C35, C36, C37, C38, C39, C40, C41, C42, C43, C44, C45, C46, C47, C48: .1uF; C_Axial_L3.8mm_D2.6mm_P7.50mm_Horizontal
C5, C20: 33uF; CP_Axial_L11.0mm_D6.0mm_P18.00mm_Horizontal
C8: 0.1u; C_Axial_L3.8mm_D2.6mm_P7.50mm_Horizontal
C14: 10pF; C_Axial_L3.8mm_D2.6mm_P7.50mm_Horizontal
C15: 33pF; C_Axial_L3.8mm_D2.6mm_P7.50mm_Horizontal
C21: .1uF; C_Axial_L5.1mm_D3.1mm_P10.00mm_Horizontal
C22: 4.7uF; CP_Axial_L11.0mm_D5.0mm_P18.00mm_Horizontal
CR1: LED; LED_D5.0mm
CR2: 1N4150; D_DO-35_SOD27_P7.62mm_Horizontal
CR3: 5.1V; D_DO-35_SOD27_P7.62mm_Horizontal
FB3: FB; L_Axial_L7.0mm_D3.3mm_P10.16mm_Horizontal_Fastron_MICC
H201, H202, H203, H204, H205, H206, H207, H208: MountingHole_Pad; MountingHole_2.7mm_M2.5_Pad
H209, H210, H211, H212, H213, H214: MountingHole; MountingHole_2.7mm_M2.5
J7: Power; Molex_KK-396_A-41791-0011_1x11_P3.96mm_Vertical
JP201: Jumper_2_Bridged; TestPoint_Bridge_Pitch5.08mm_Drill0.7mm
L1, L3: 28uH; L_Toroid_Vertical_L14.0mm_W5.6mm_P5.30mm_Bourns_5700
L2: 27uH; L_Axial_L7.0mm_D3.3mm_P10.16mm_Horizontal_Fastron_MICC
Q1: LM7905_TO220; TO-220-3_Horizontal_TabDown_HS
R3, R9, R21: 1.0k; R_Axial_DIN0207_L6.3mm_D2.5mm_P7.62mm_Horizontal
R11: 150; R_Axial_DIN0207_L6.3mm_D2.5mm_P7.62mm_Horizontal
R23: 100k; R_Axial_DIN0207_L6.3mm_D2.5mm_P7.62mm_Horizontal
R28: 3.3k; R_Axial_DIN0207_L6.3mm_D2.5mm_P7.62mm_Horizontal
R32: 75; R_Axial_DIN0207_L6.3mm_D2.5mm_P7.62mm_Horizontal
SW2: RESET; TL1100CF160Q
U2B201: 15.6672MHz; Oscillator_DIP-14
U4D201: 74LS04; DIP-14_W7.62mm_Socket_LongPads
U7C201: LM311; DIP-8_W7.62mm_Socket_LongPads
U15B201: 344-0040; DIP-8_W7.62mm_Socket_LongPads
Y1: 32.768kHz; Crystal_C26-LF_D2.1mm_L6.5mm_Horizontal

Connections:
+5V: C5.1, C8.2, C9.1, C17.1, C21.1, C23.1, C24.1, C25.1, C26.1, C27.1, C28.1, C29.1, C30.1, C31.1, C32.1, C33.1, C34.1, C35.1, C36.1, C37.1, C38.1, C39.1, C40.1, C41.1, C42.1, C43.1, C44.1, C45.1, C46.1, C47.1, C48.1, CR1.2 (A), J7.6, L3.1, R9.1, R28.1, U2B201.14 (Vcc), U4D201.14 (VCC); also elsewhere on the board
+5VA: C4.1, L3.2; also elsewhere on the board
+5VL: C13.1, CR3.1 (K), R21.2; also elsewhere on the board
+12V: C22.1, J7.10, L1.1, R3.1, R21.1, U7C201.8 (V+); also elsewhere on the board
+12VA: C3.1, L1.2; also elsewhere on the board
+BATT: C16.1, J7.11, U15B201.8 (Vdd)
-5V: C20.2, Q1.3 (VO), R23.2, U7C201.4 (V-); also elsewhere on the board
-12V: J7.8, L2.1, Q1.2 (VI); also elsewhere on the board
-12VA: C2.1, L2.2; also elsewhere on the board
A20: R28.2, U4D201.5; also elsewhere on the board
C16M: FB3.2, U4D201.2; also elsewhere on the board
C16MF: FB3.1; also elsewhere on the board
DMA: U4D201.4; also elsewhere on the board
Earth: C2.2, C3.2, C4.2, H201.1, H202.1, H203.1, H204.1, H205.1, H206.1, H207.1, H208.1, JP201.2 (B); also elsewhere on the board
GND: C5.2, C8.1, C9.2, C13.2, C14.2, C15.2, C16.2, C17.2, C20.1, C21.2, C23.2, C24.2, C25.2, C26.2, C27.2, C28.2, C29.2, C30.2, C31.2, C32.2, C33.2, C34.2, C35.2, C36.2, C37.2, C38.2, C39.2, C40.2, C41.2, C42.2, C43.2, C44.2, C45.2, C46.2, C47.2, C48.2, CR2.2 (A), CR3.2 (A), J7.7, J7.9, JP201.1 (A), Q1.1 (GND), R11.2, U2B201.7 (GND), U4D201.7 (GND), U7C201.1 (GND), U15B201.4 (Vss); also elsewhere on the board
unnamed: C14.1, U15B201.3 (X2), Y1.1
unnamed: C15.1, U15B201.2 (X1), Y1.2
unnamed: C22.2, CR2.1 (K), R23.1, SW2.1, U7C201.3 (-)
unnamed: CR1.1 (K), R11.1
unnamed: J7.1, R32.1
unnamed: R3.2, SW2.2
ONESEC: U15B201.1 (1SEC); also elsewhere on the board
RTC_CLK: U15B201.7 (CLK); also elsewhere on the board
RTC_DATA: U15B201.6 (DATA); also elsewhere on the board
SND: U4D201.11; also elsewhere on the board
SNDRES: U4D201.9; also elsewhere on the board
SPKR: J7.4; also elsewhere on the board
WR: U4D201.12; also elsewhere on the board
/A20: U4D201.6; also elsewhere on the board
/C16M: U2B201.8 (OUT), U4D201.1
/DMA: U4D201.3; also elsewhere on the board
/HSYNC: J7.3; also elsewhere on the board
/RES: R9.2, U7C201.2 (+), U7C201.7; also elsewhere on the board
/RTC: U15B201.5 (/EN); also elsewhere on the board
/SND: U4D201.10; also elsewhere on the board
/SNDRES: U4D201.8; also elsewhere on the board
/VIDOUT: R32.2; also elsewhere on the board
/VSYNC: J7.5; also elsewhere on the board
/WR: U4D201.13; also elsewhere on the board

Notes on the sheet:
Apple ASIC: RTC (from Apple //gs)
Bypass caps C9, C17, C21 C23-C48
Power Supply
POWER
+5REF
Optional
COLD
Real-time Clock
NOTE: L1/L3 are vertical torroidal inductors. The 128k board had a "vertical" footprint but the coils were laid flat. Later boards were horizontal footprints.
Single-point Ground
KEY
H6 on the prototype is used as the SPG point. Holes aren't numbered, but it looks like there is a wide trace near C5 for this. KiCAD doesn't seem to allow a trace jumper like this, so going with a zero-ohm resistor there.
TTL
Reset
Switch: Diptronics DTSA-25R-V
System Clock

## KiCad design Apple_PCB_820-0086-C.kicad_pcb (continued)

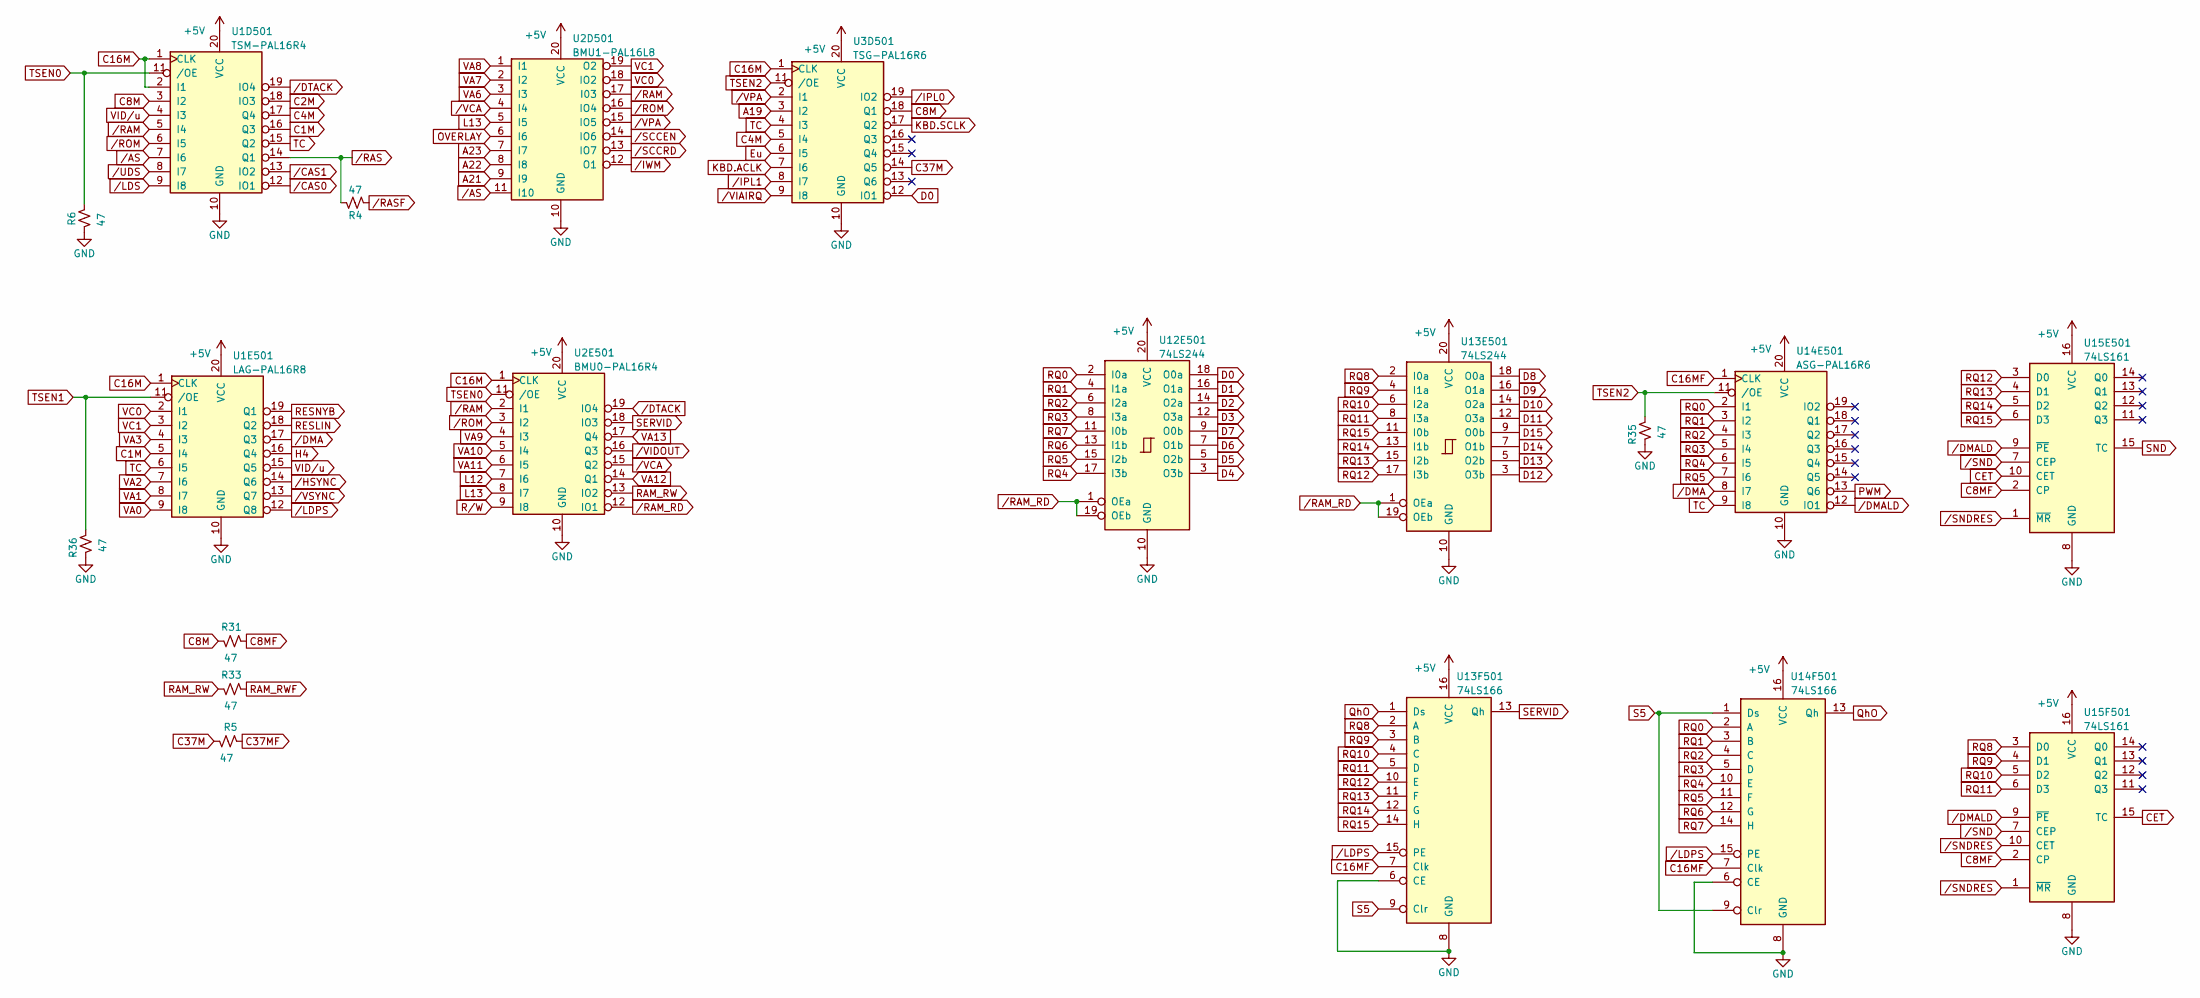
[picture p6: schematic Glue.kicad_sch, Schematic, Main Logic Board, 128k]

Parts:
R4, R5, R6, R31, R33, R35, R36: 47; R_Axial_DIN0207_L6.3mm_D2.5mm_P7.62mm_Horizontal
U1D501: TSM-PAL16R4; DIP-20_W7.62mm_Socket_LongPads
U1E501: LAG-PAL16R8; DIP-20_W7.62mm_Socket_LongPads
U2D501: BMU1-PAL16L8; DIP-20_W7.62mm_Socket_LongPads
U2E501: BMU0-PAL16R4; DIP-20_W7.62mm_Socket_LongPads
U3D501: TSG-PAL16R6; DIP-20_W7.62mm_Socket_LongPads
U12E501, U13E501: 74LS244; DIP-20_W7.62mm_Socket_LongPads
U13F501, U14F501: 74LS166; DIP-16_W7.62mm_Socket_LongPads
U14E501: ASG-PAL16R6; DIP-20_W7.62mm_Socket_LongPads
U15E501, U15F501: 74LS161; DIP-16_W7.62mm_Socket_LongPads

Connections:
+5V: U1D501.20 (VCC), U1E501.20 (VCC), U2D501.20 (VCC), U2E501.20 (VCC), U3D501.20 (VCC), U12E501.20 (VCC), U13E501.20 (VCC), U13F501.16 (VCC), U14E501.20 (VCC), U14F501.16 (VCC), U15E501.16 (VCC), U15F501.16 (VCC); also elsewhere on the board
A19: U3D501.3 (I2); also elsewhere on the board
A21: U2D501.9 (I9); also elsewhere on the board
A22: U2D501.8 (I8); also elsewhere on the board
A23: U2D501.7 (I7); also elsewhere on the board
C1M: U1D501.16 (Q3), U1E501.5 (I4)
C2M: U1D501.18 (IO3); also elsewhere on the board
C4M: U1D501.17 (Q4), U3D501.5 (I4)
C8M: R31.1, U1D501.3 (I2), U3D501.18 (Q1)
C8MF: R31.2, U15E501.2 (CP), U15F501.2 (CP); also elsewhere on the board
C16M: U1D501.1 (CLK), U1D501.2 (I1), U1E501.1 (CLK), U2E501.1 (CLK), U3D501.1 (CLK); also elsewhere on the board
C16MF: U13F501.7 (Clk), U14E501.1 (CLK), U14F501.7 (Clk); also elsewhere on the board
C37M: R5.1, U3D501.14 (Q5)
C37MF: R5.2; also elsewhere on the board
CET: U15E501.10 (CET), U15F501.15 (TC)
D0: U3D501.12 (IO1), U12E501.18 (O0a); also elsewhere on the board
D1: U12E501.16 (O1a); also elsewhere on the board
D2: U12E501.14 (O2a); also elsewhere on the board
D3: U12E501.12 (O3a); also elsewhere on the board
D4: U12E501.3 (O3b); also elsewhere on the board
D5: U12E501.5 (O2b); also elsewhere on the board
D6: U12E501.7 (O1b); also elsewhere on the board
D7: U12E501.9 (O0b); also elsewhere on the board
D8: U13E501.18 (O0a); also elsewhere on the board
D9: U13E501.16 (O1a); also elsewhere on the board
D10: U13E501.14 (O2a); also elsewhere on the board
D11: U13E501.12 (O3a); also elsewhere on the board
D12: U13E501.3 (O3b); also elsewhere on the board
D13: U13E501.5 (O2b); also elsewhere on the board
D14: U13E501.7 (O1b); also elsewhere on the board
D15: U13E501.9 (O0b); also elsewhere on the board
Eu: U3D501.6 (I5); also elsewhere on the board
GND: R6.1, R35.1, R36.1, U1D501.10 (GND), U1E501.10 (GND), U2D501.10 (GND), U2E501.10 (GND), U3D501.10 (GND), U12E501.10 (GND), U13E501.10 (GND), U13F501.6 (CE), U13F501.8 (GND), U14E501.10 (GND), U14F501.6 (CE), U14F501.8 (GND), U15E501.8 (GND), U15F501.8 (GND); also elsewhere on the board
H4: U1E501.16 (Q4); also elsewhere on the board
KBD.ACLK: U3D501.7 (I6); also elsewhere on the board
KBD.SCLK: U3D501.17 (Q2); also elsewhere on the board
L12: U2E501.7 (I6); also elsewhere on the board
L13: U2D501.5 (I5), U2E501.8 (I7); also elsewhere on the board
OVERLAY: U2D501.6 (I6); also elsewhere on the board
PWM: U14E501.13 (Q6); also elsewhere on the board
QhO: U13F501.1 (Ds), U14F501.13 (Qh)
RAM_RW: R33.1, U2E501.13 (IO2)
RAM_RWF: R33.2; also elsewhere on the board
RESLIN: U1E501.18 (Q2); also elsewhere on the board
RESNYB: U1E501.19 (Q1); also elsewhere on the board
RQ0: U12E501.2 (I0a), U14E501.2 (I1), U14F501.2 (A); also elsewhere on the board
RQ1: U12E501.4 (I1a), U14E501.3 (I2), U14F501.3 (B); also elsewhere on the board
RQ2: U12E501.6 (I2a), U14E501.4 (I3), U14F501.4 (C); also elsewhere on the board
RQ3: U12E501.8 (I3a), U14E501.5 (I4), U14F501.5 (D); also elsewhere on the board
RQ4: U12E501.17 (I3b), U14E501.6 (I5), U14F501.10 (E); also elsewhere on the board
RQ5: U12E501.15 (I2b), U14E501.7 (I6), U14F501.11 (F); also elsewhere on the board
RQ6: U12E501.13 (I1b), U14F501.12 (G); also elsewhere on the board
RQ7: U12E501.11 (I0b), U14F501.14 (H); also elsewhere on the board
RQ8: U13E501.2 (I0a), U13F501.2 (A), U15F501.3 (D0); also elsewhere on the board
RQ9: U13E501.4 (I1a), U13F501.3 (B), U15F501.4 (D1); also elsewhere on the board
RQ10: U13E501.6 (I2a), U13F501.4 (C), U15F501.5 (D2); also elsewhere on the board
RQ11: U13E501.8 (I3a), U13F501.5 (D), U15F501.6 (D3); also elsewhere on the board
RQ12: U13E501.17 (I3b), U13F501.10 (E), U15E501.3 (D0); also elsewhere on the board
RQ13: U13E501.15 (I2b), U13F501.11 (F), U15E501.4 (D1); also elsewhere on the board
RQ14: U13E501.13 (I1b), U13F501.12 (G), U15E501.5 (D2); also elsewhere on the board
RQ15: U13E501.11 (I0b), U13F501.14 (H), U15E501.6 (D3); also elsewhere on the board
R/W: U2E501.9 (I8); also elsewhere on the board
S5: U13F501.9 (Clr), U14F501.1 (Ds), U14F501.9 (Clr); also elsewhere on the board
SERVID: U2E501.18 (IO3), U13F501.13 (Qh)
SND: U15E501.15 (TC); also elsewhere on the board
TC: U1D501.15 (Q2), U1E501.6 (I5), U3D501.4 (I3), U14E501.9 (I8); also elsewhere on the board
TSEN0: R6.2, U1D501.11 (/OE), U2E501.11 (/OE)
TSEN1: R36.2, U1E501.11 (/OE)
TSEN2: R35.2, U3D501.11 (/OE), U14E501.11 (/OE)
VA0: U1E501.9 (I8); also elsewhere on the board
VA1: U1E501.8 (I7); also elsewhere on the board
VA2: U1E501.7 (I6); also elsewhere on the board
VA3: U1E501.4 (I3); also elsewhere on the board
VA6: U2D501.3 (I3); also elsewhere on the board
VA7: U2D501.2 (I2); also elsewhere on the board
VA8: U2D501.1 (I1); also elsewhere on the board
VA9: U2E501.4 (I3); also elsewhere on the board
VA10: U2E501.5 (I4); also elsewhere on the board
VA11: U2E501.6 (I5); also elsewhere on the board
VA12: U2E501.14 (Q1); also elsewhere on the board
VA13: U2E501.17 (Q4); also elsewhere on the board
VC0: U1E501.2 (I1), U2D501.18 (IO2)
VC1: U1E501.3 (I2), U2D501.19 (O2)
VID/u: U1D501.4 (I3), U1E501.15 (Q5); also elsewhere on the board
/AS: U1D501.7 (I6), U2D501.11 (I10); also elsewhere on the board
/CAS0: U1D501.12 (IO1); also elsewhere on the board
/CAS1: U1D501.13 (IO2); also elsewhere on the board
/DMA: U1E501.17 (Q3), U14E501.8 (I7); also elsewhere on the board
/DMALD: U14E501.12 (IO1), U15E501.9 (~PE), U15F501.9 (~PE)
/DTACK: U1D501.19 (IO4), U2E501.19 (IO4); also elsewhere on the board
/HSYNC: U1E501.14 (Q6); also elsewhere on the board
/IPL0: U3D501.19 (IO2); also elsewhere on the board
/IPL1: U3D501.8 (I7); also elsewhere on the board
/IWM: U2D501.12 (O1); also elsewhere on the board
/LDPS: U1E501.12 (Q8), U13F501.15 (PE), U14F501.15 (PE)
/LDS: U1D501.9 (I8); also elsewhere on the board
/RAM: U1D501.5 (I4), U2D501.17 (I03), U2E501.2 (I1)
/RAM_RD: U2E501.12 (IO1), U12E501.1 (OEa), U12E501.19 (OEb), U13E501.1 (OEa), U13E501.19 (OEb)
/RAS: R4.2, U1D501.14 (Q1)
/RASF: R4.1; also elsewhere on the board
/ROM: U1D501.6 (I5), U2D501.16 (IO4), U2E501.3 (I2); also elsewhere on the board
/SCCEN: U2D501.14 (IO6); also elsewhere on the board
/SCCRD: U2D501.13 (IO7); also elsewhere on the board
/SND: U15E501.7 (CEP), U15F501.7 (CEP); also elsewhere on the board
/SNDRES: U15E501.1 (~MR), U15F501.1 (~MR), U15F501.10 (CET); also elsewhere on the board
/UDS: U1D501.8 (I7); also elsewhere on the board
/VCA: U2D501.4 (I4), U2E501.15 (Q2)
/VIAIRQ: U3D501.9 (I8); also elsewhere on the board
/VIDOUT: U2E501.16 (Q3); also elsewhere on the board
/VPA: U2D501.15 (IO5), U3D501.2 (I1); also elsewhere on the board
/VSYNC: U1E501.13 (Q7); also elsewhere on the board

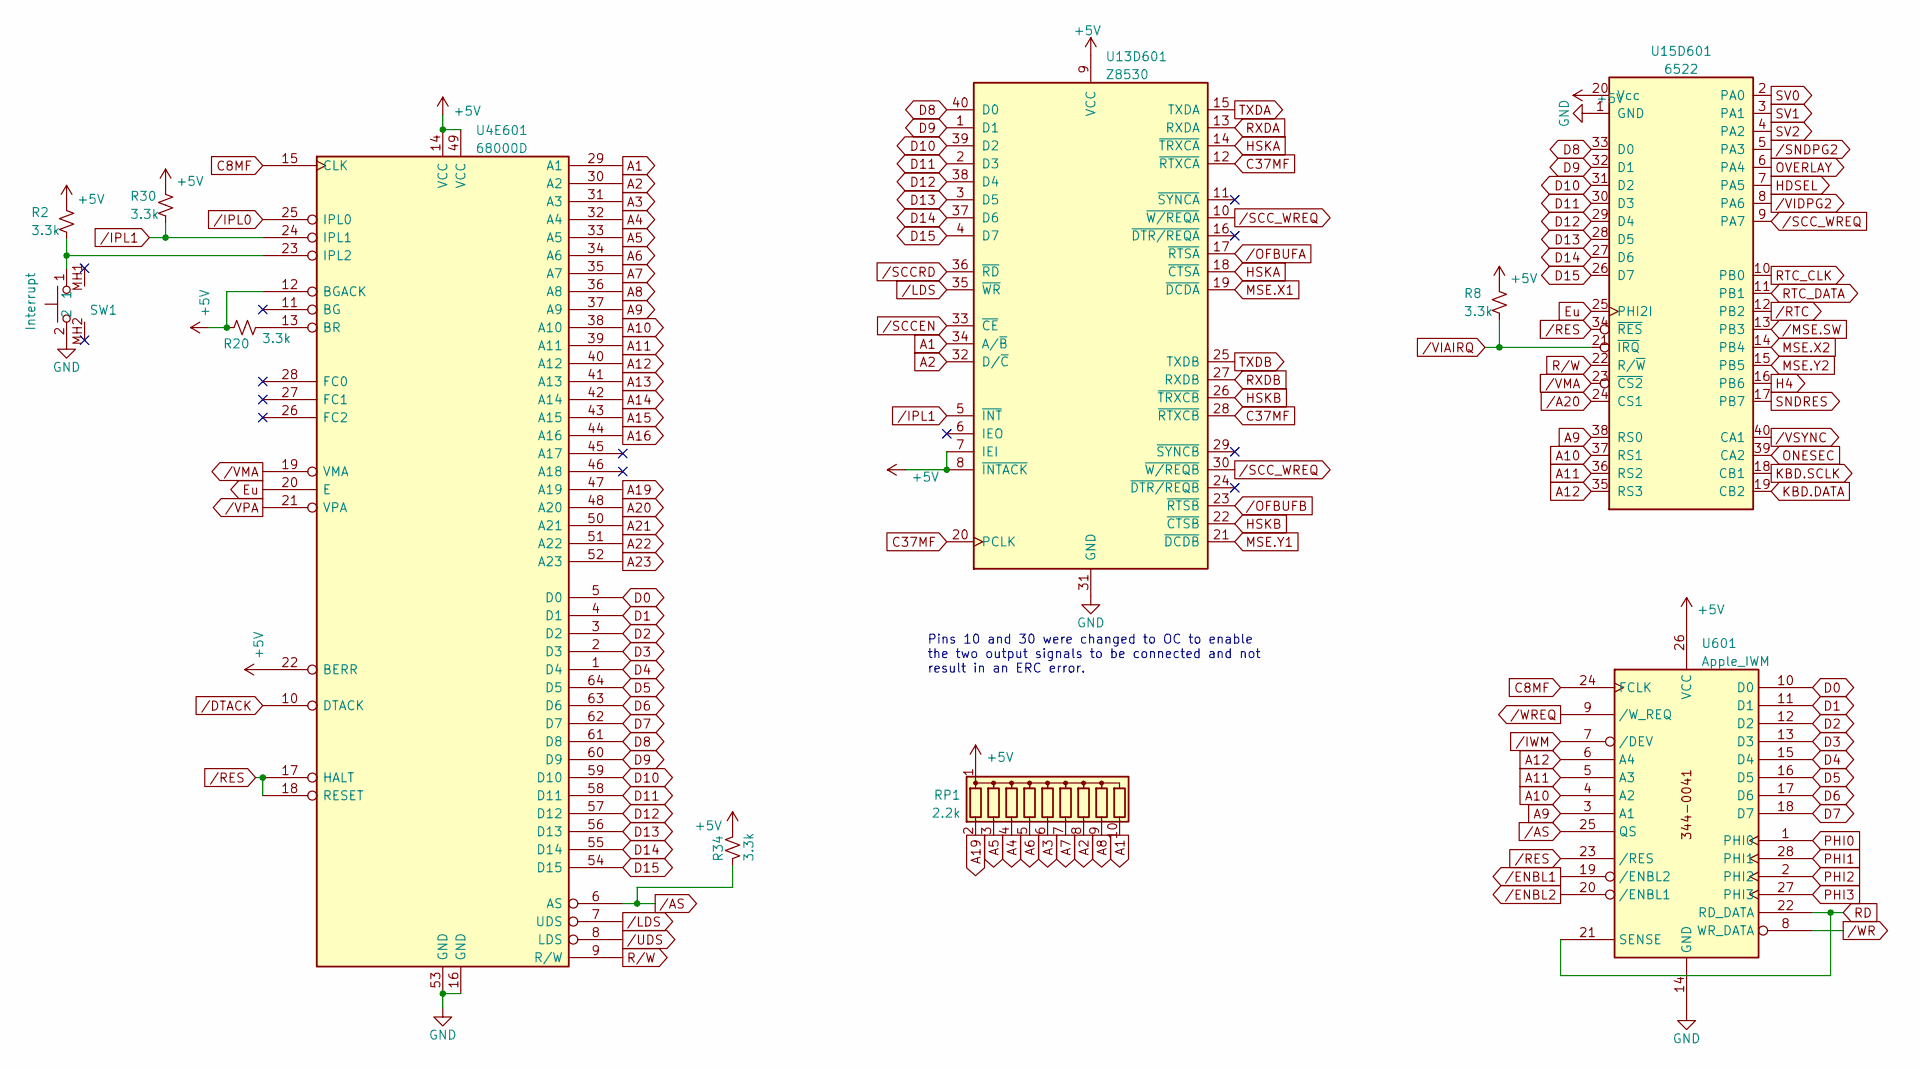
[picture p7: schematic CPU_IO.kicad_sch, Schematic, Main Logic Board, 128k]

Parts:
R2, R8, R20, R30, R34: 3.3k; R_Axial_DIN0207_L6.3mm_D2.5mm_P7.62mm_Horizontal
RP1: 2.2k; R_Array_SIP10
SW1: Interrupt; TL1100CF160Q
U4E601: 68000D; DIP-64_W22.86mm_Socket_LongPads
U13D601: Z8530; DIP-40_W15.24mm_Socket_LongPads
U15D601: 6522; DIP-40_W15.24mm_Socket_LongPads
U601: Apple_IWM; DIP-28_W15.24mm_Socket_LongPads

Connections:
+5V: R2.1, R8.1, R20.1, R30.1, R34.1, RP1.1 (common), U4E601.12 (BGACK), U4E601.14 (VCC), U4E601.22 (BERR), U4E601.49 (VCC), U13D601.7 (IEI), U13D601.8 (~INTACK), U13D601.9 (VCC), U15D601.20 (Vcc), U601.26 (VCC); also elsewhere on the board
A1: RP1.10 (R9), U4E601.29 (A1), U13D601.34 (A/~B); also elsewhere on the board
A2: RP1.8 (R7), U4E601.30 (A2), U13D601.32 (D/~C); also elsewhere on the board
A3: RP1.6 (R5), U4E601.31 (A3); also elsewhere on the board
A4: RP1.4 (R3), U4E601.32 (A4); also elsewhere on the board
A5: RP1.3 (R2), U4E601.33 (A5); also elsewhere on the board
A6: RP1.5 (R4), U4E601.34 (A6); also elsewhere on the board
A7: RP1.7 (R6), U4E601.35 (A7); also elsewhere on the board
A8: RP1.9 (R8), U4E601.36 (A8); also elsewhere on the board
A9: U4E601.37 (A9), U15D601.38 (RS0), U601.3 (A1); also elsewhere on the board
A10: U4E601.38 (A10), U15D601.37 (RS1), U601.4 (A2); also elsewhere on the board
A11: U4E601.39 (A11), U15D601.36 (RS2), U601.5 (A3); also elsewhere on the board
A12: U4E601.40 (A12), U15D601.35 (RS3), U601.6 (A4); also elsewhere on the board
A13: U4E601.41 (A13); also elsewhere on the board
A14: U4E601.42 (A14); also elsewhere on the board
A15: U4E601.43 (A15); also elsewhere on the board
A16: U4E601.44 (A16); also elsewhere on the board
A19: RP1.2 (R1), U4E601.47 (A19); also elsewhere on the board
A20: U4E601.48 (A20); also elsewhere on the board
A21: U4E601.50 (A21); also elsewhere on the board
A22: U4E601.51 (A22); also elsewhere on the board
A23: U4E601.52 (A23); also elsewhere on the board
C8MF: U4E601.15 (CLK), U601.24 (FCLK); also elsewhere on the board
C37MF: U13D601.12 (~RTXCA), U13D601.20 (PCLK), U13D601.28 (~RTXCB); also elsewhere on the board
D0: U4E601.5 (D0), U601.10 (D0); also elsewhere on the board
D1: U4E601.4 (D1), U601.11 (D1); also elsewhere on the board
D2: U4E601.3 (D2), U601.12 (D2); also elsewhere on the board
D3: U4E601.2 (D3), U601.13 (D3); also elsewhere on the board
D4: U4E601.1 (D4), U601.15 (D4); also elsewhere on the board
D5: U4E601.64 (D5), U601.16 (D5); also elsewhere on the board
D6: U4E601.63 (D6), U601.17 (D6); also elsewhere on the board
D7: U4E601.62 (D7), U601.18 (D7); also elsewhere on the board
D8: U4E601.61 (D8), U13D601.40 (D0), U15D601.33 (D0); also elsewhere on the board
D9: U4E601.60 (D9), U13D601.1 (D1), U15D601.32 (D1); also elsewhere on the board
D10: U4E601.59 (D10), U13D601.39 (D2), U15D601.31 (D2); also elsewhere on the board
D11: U4E601.58 (D11), U13D601.2 (D3), U15D601.30 (D3); also elsewhere on the board
D12: U4E601.57 (D12), U13D601.38 (D4), U15D601.29 (D4); also elsewhere on the board
D13: U4E601.56 (D13), U13D601.3 (D5), U15D601.28 (D5); also elsewhere on the board
D14: U4E601.55 (D14), U13D601.37 (D6), U15D601.27 (D6); also elsewhere on the board
D15: U4E601.54 (D15), U13D601.4 (D7), U15D601.26 (D7); also elsewhere on the board
Eu: U4E601.20 (E), U15D601.25 (PHI2I); also elsewhere on the board
GND: SW1.2, U4E601.16 (GND), U4E601.53 (GND), U13D601.31 (GND), U15D601.1 (GND), U601.14 (GND); also elsewhere on the board
H4: U15D601.16 (PB6); also elsewhere on the board
HDSEL: U15D601.7 (PA5); also elsewhere on the board
HSKA: U13D601.14 (~TRXCA), U13D601.18 (~CTSA); also elsewhere on the board
HSKB: U13D601.22 (~CTSB), U13D601.26 (~TRXCB); also elsewhere on the board
KBD.DATA: U15D601.19 (CB2); also elsewhere on the board
KBD.SCLK: U15D601.18 (CB1); also elsewhere on the board
MSE.X1: U13D601.19 (~DCDA); also elsewhere on the board
MSE.X2: U15D601.14 (PB4); also elsewhere on the board
MSE.Y1: U13D601.21 (~DCDB); also elsewhere on the board
MSE.Y2: U15D601.15 (PB5); also elsewhere on the board
unnamed: R2.2, SW1.1, U4E601.23 (IPL2)
unnamed: R20.2, U4E601.13 (BR)
ONESEC: U15D601.39 (CA2); also elsewhere on the board
OVERLAY: U15D601.6 (PA4); also elsewhere on the board
PHI0: U601.1 (PHI0); also elsewhere on the board
PHI1: U601.28 (PHI1); also elsewhere on the board
PHI2: U601.2 (PHI2); also elsewhere on the board
PHI3: U601.27 (PHI3); also elsewhere on the board
RD: U601.21 (SENSE), U601.22 (RD_DATA); also elsewhere on the board
RTC_CLK: U15D601.10 (PB0); also elsewhere on the board
RTC_DATA: U15D601.11 (PB1); also elsewhere on the board
RXDA: U13D601.13 (RXDA); also elsewhere on the board
RXDB: U13D601.27 (RXDB); also elsewhere on the board
R/W: U4E601.9 (R/W), U15D601.22 (R/~W); also elsewhere on the board
SNDRES: U15D601.17 (PB7); also elsewhere on the board
SV0: U15D601.2 (PA0); also elsewhere on the board
SV1: U15D601.3 (PA1); also elsewhere on the board
SV2: U15D601.4 (PA2); also elsewhere on the board
TXDA: U13D601.15 (TXDA); also elsewhere on the board
TXDB: U13D601.25 (TXDB); also elsewhere on the board
/A20: U15D601.24 (CS1); also elsewhere on the board
/AS: R34.2, U4E601.6 (AS), U601.25 (QS); also elsewhere on the board
/DTACK: U4E601.10 (DTACK); also elsewhere on the board
/ENBL1: U601.19 (/ENBL2); also elsewhere on the board
/ENBL2: U601.20 (/ENBL1); also elsewhere on the board
/IPL0: U4E601.25 (IPL0); also elsewhere on the board
/IPL1: R30.2, U4E601.24 (IPL1), U13D601.5 (~INT); also elsewhere on the board
/IWM: U601.7 (/DEV); also elsewhere on the board
/LDS: U4E601.7 (UDS), U13D601.35 (~WR); also elsewhere on the board
/MSE.SW: U15D601.13 (PB3); also elsewhere on the board
/OFBUFA: U13D601.17 (~RTSA); also elsewhere on the board
/OFBUFB: U13D601.23 (~RTSB); also elsewhere on the board
/RES: U4E601.17 (HALT), U4E601.18 (RESET), U15D601.34 (~RES), U601.23 (/RES); also elsewhere on the board
/RTC: U15D601.12 (PB2); also elsewhere on the board
/SCCEN: U13D601.33 (~CE); also elsewhere on the board
/SCCRD: U13D601.36 (~RD); also elsewhere on the board
/SCC_WREQ: U13D601.10 (~W/REQA), U13D601.30 (~W/REQB), U15D601.9 (PA7)
/SNDPG2: U15D601.5 (PA3); also elsewhere on the board
/UDS: U4E601.8 (LDS); also elsewhere on the board
/VIAIRQ: R8.2, U15D601.21 (~IRQ); also elsewhere on the board
/VIDPG2: U15D601.8 (PA6); also elsewhere on the board
/VMA: U4E601.19 (VMA), U15D601.23 (~CS2)
/VPA: U4E601.21 (VPA); also elsewhere on the board
/VSYNC: U15D601.40 (CA1); also elsewhere on the board
/WR: U601.8 (WR_DATA); also elsewhere on the board
/WREQ: U601.9 (/W_REQ); also elsewhere on the board

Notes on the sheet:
Pins 10 and 30 were changed to OC to enable the two output signals to be connected and not result in an ERC error.

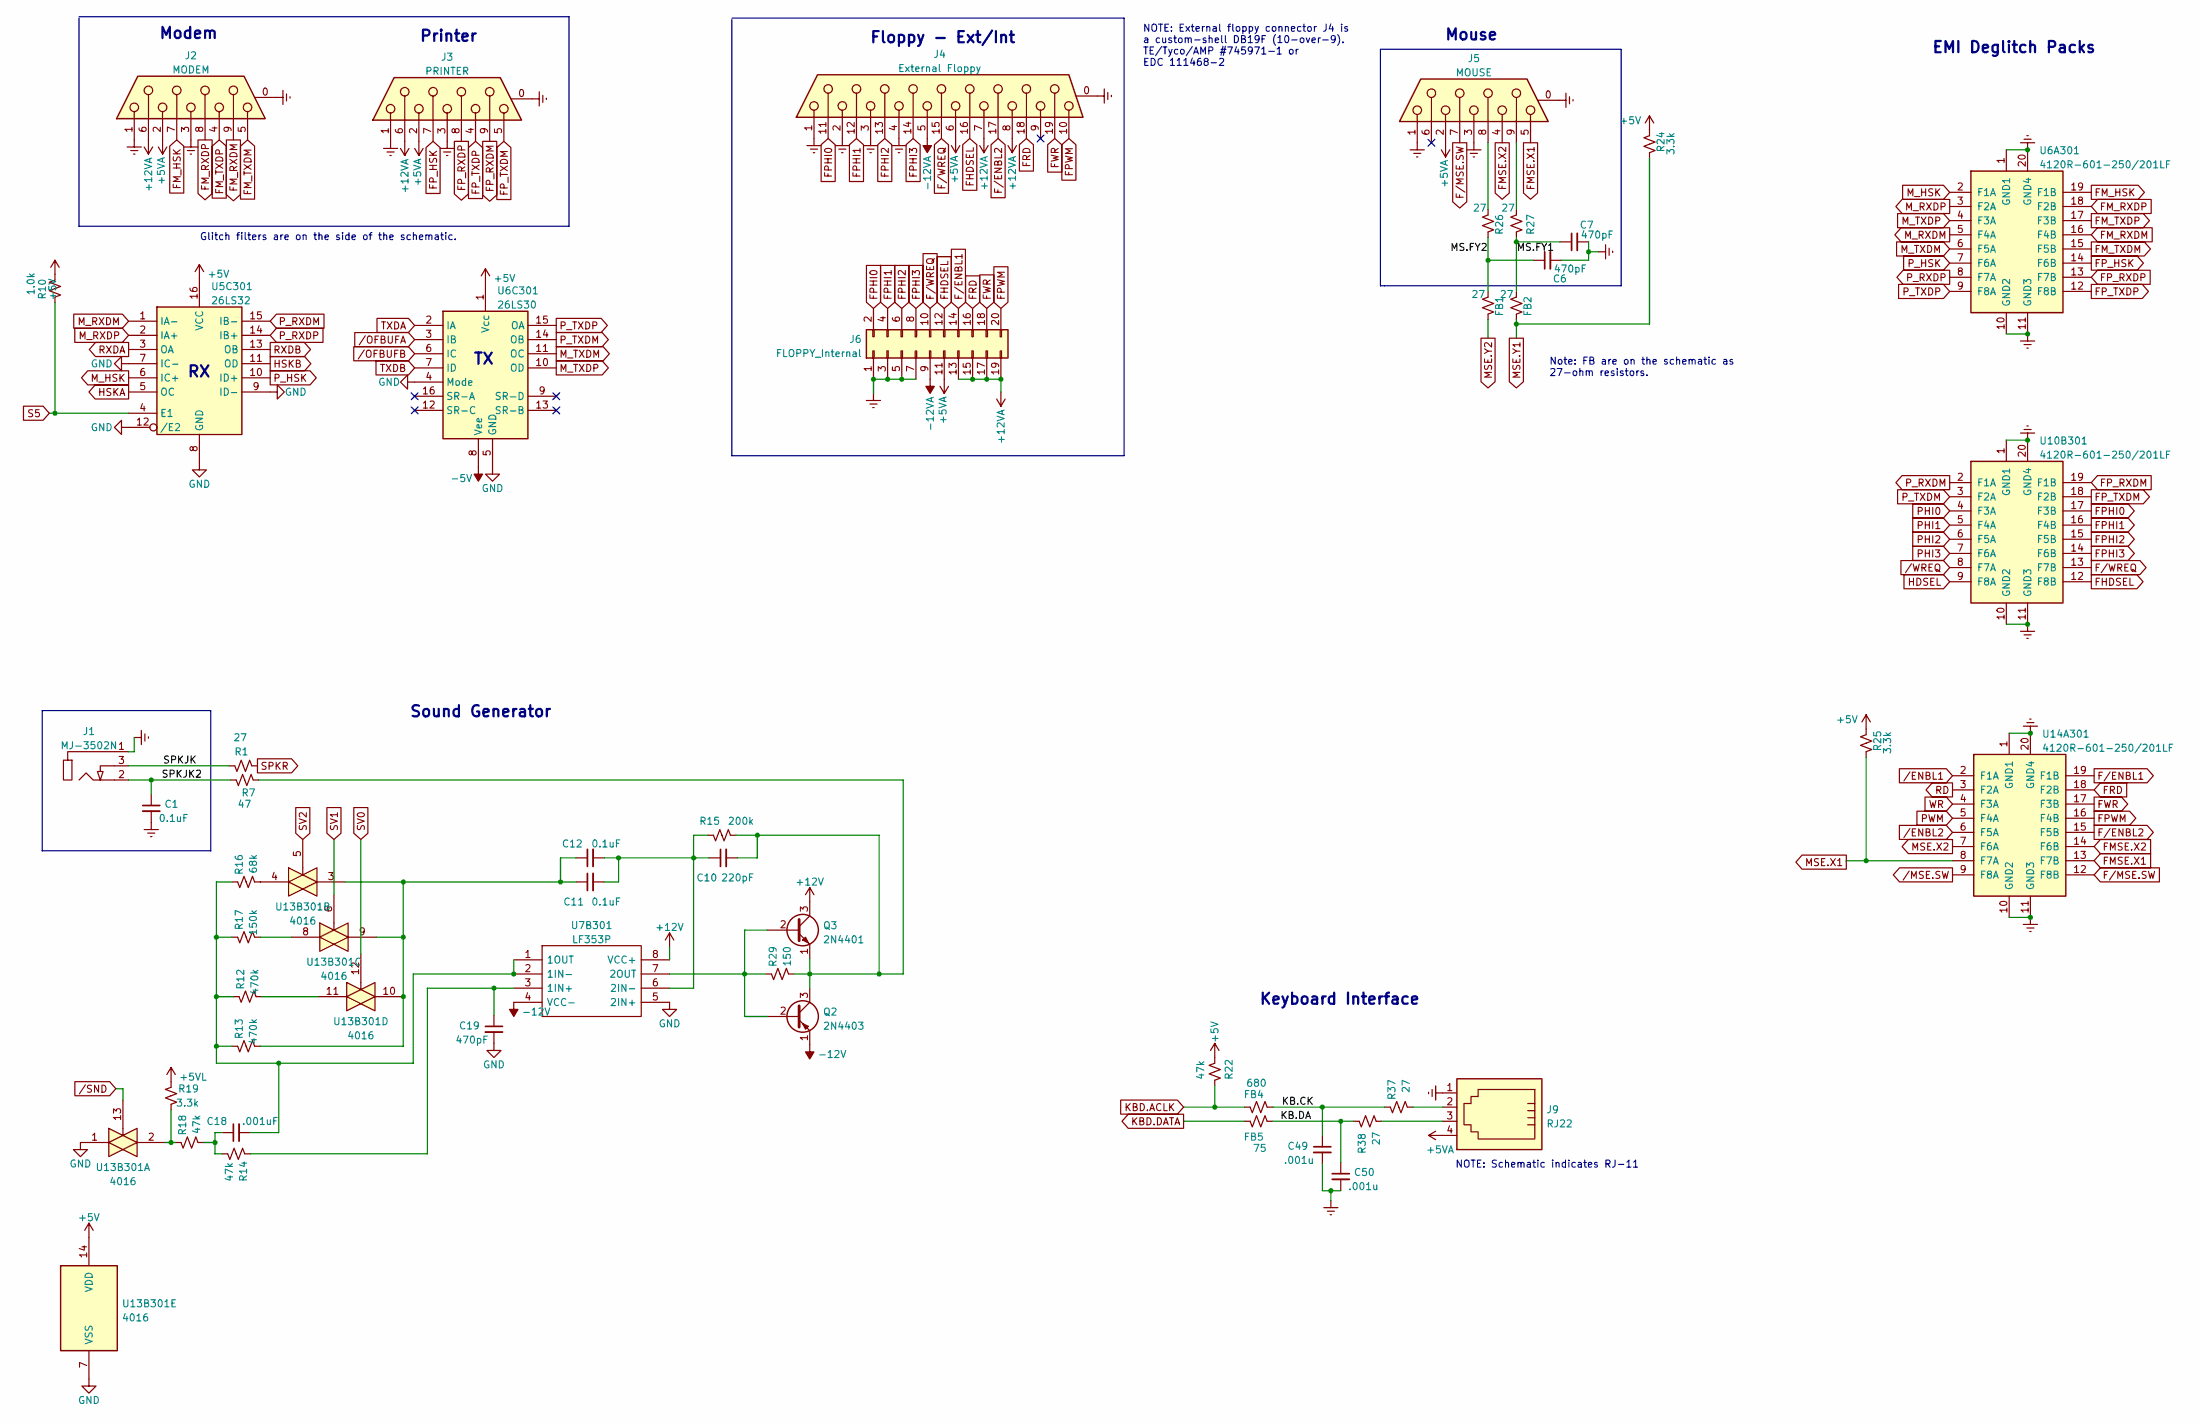
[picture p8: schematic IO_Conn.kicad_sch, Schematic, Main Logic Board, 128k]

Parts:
C1, C11, C12: 0.1uF; C_Axial_L3.8mm_D2.6mm_P7.50mm_Horizontal
C6, C7, C19: 470pF; C_Axial_L3.8mm_D2.6mm_P7.50mm_Horizontal
C10: 220pF; C_Axial_L3.8mm_D2.6mm_P7.50mm_Horizontal
C18: .001uF; C_Axial_L3.8mm_D2.6mm_P7.50mm_Horizontal
C49, C50: .001u; C_Axial_L3.8mm_D2.6mm_P7.50mm_Horizontal
FB1, FB2: 27; R_Axial_DIN0207_L6.3mm_D2.5mm_P7.62mm_Horizontal
FB4: 680; R_Axial_DIN0207_L6.3mm_D2.5mm_P7.62mm_Horizontal
FB5: 75; R_Axial_DIN0207_L6.3mm_D2.5mm_P7.62mm_Horizontal
J1: MJ-3502N; MJ3502N; Mouser Part Number 490-MJ-3502N
J2: MODEM; DSUB-9_Female_Horizontal_P2.77x2.84mm_EdgePinOffset4.94mm_H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
J3: PRINTER; DSUB-9_Female_Horizontal_P2.77x2.84mm_EdgePinOffset4.94mm_H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
J4: External Floppy; DSUB-19_Female_Horizontal_P2.77x2.84mm_EdgePinOffset7.70mm_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
J5: MOUSE; DSUB-9_Female_Horizontal_P2.77x2.84mm_EdgePinOffset4.94mm_H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
J6: FLOPPY_Internal; IDC-Header_2x10_P2.54mm_Vertical
J9: RJ22; 55559801
Q2: 2N4403; TO-92_Inline
Q3: 2N4401; TO-92_Inline
R1, R26, R27, R37, R38: 27; R_Axial_DIN0207_L6.3mm_D2.5mm_P7.62mm_Horizontal
R7: 47; R_Axial_DIN0207_L6.3mm_D2.5mm_P7.62mm_Horizontal
R10: 1.0k; R_Axial_DIN0207_L6.3mm_D2.5mm_P7.62mm_Horizontal
R12, R13: 470k; R_Axial_DIN0207_L6.3mm_D2.5mm_P7.62mm_Horizontal
R14, R18, R22: 47k; R_Axial_DIN0207_L6.3mm_D2.5mm_P7.62mm_Horizontal
R15: 200k; R_Axial_DIN0207_L6.3mm_D2.5mm_P7.62mm_Horizontal
R16: 68k; R_Axial_DIN0207_L6.3mm_D2.5mm_P7.62mm_Horizontal
R17: 150k; R_Axial_DIN0207_L6.3mm_D2.5mm_P7.62mm_Horizontal
R19, R24, R25: 3.3k; R_Axial_DIN0207_L6.3mm_D2.5mm_P7.62mm_Horizontal
R29: 150; R_Axial_DIN0207_L6.3mm_D2.5mm_P7.62mm_Horizontal
U5C301: 26LS32; DIP-16_W7.62mm_Socket_LongPads
U6A301, U10B301, U14A301: 4120R-601-250/201LF; DIP-20_W7.62mm_Socket_LongPads
U6C301: 26LS30; DIP-16_W7.62mm_Socket_LongPads
U7B301: LF353P; DIP-8_W7.62mm_Socket_LongPads; Mouser Part Number 595-LF353P
U13B301: 4016; DIP-14_W7.62mm_Socket_LongPads

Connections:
+5V: R10.1, R22.1, R24.1, R25.1, U5C301.16 (VCC), U6C301.1 (Vcc), U13B301.14 (VDD); also elsewhere on the board
+5VA: J2.2, J3.2, J4.6, J5.2, J6.11, J9.4; also elsewhere on the board
+5VL: R19.1; also elsewhere on the board
+12V: Q3.3 (C), U7B301.8 (VCC+); also elsewhere on the board
+12VA: J2.6, J3.6, J4.7, J4.8, J6.13, J6.15, J6.17, J6.19; also elsewhere on the board
-5V: U6C301.8 (Vee); also elsewhere on the board
-12V: Q2.1 (E), U7B301.4 (VCC-); also elsewhere on the board
-12VA: J4.5, J6.9; also elsewhere on the board
/IO Connectors/KB.CK: C49.1, FB4.2, R37.1
/IO Connectors/KB.DA: C50.1, FB5.2, R38.1
/IO Connectors/MS.FY1: C7.1, FB2.2, R27.1
/IO Connectors/MS.FY2: C6.1, FB1.2, R26.1
/IO Connectors/SPKJK: J1.3, R1.1
/IO Connectors/SPKJK2: C1.1, J1.2, R7.1
Earth: C1.2, C6.2, C7.2, C49.2, C50.2, J1.1, J2.0 (PAD), J2.1, J2.3, J3.0 (PAD), J3.1, J3.3, J4.0 (PAD), J4.1, J4.2, J4.3, J4.4, J5.0 (PAD), J5.1, J5.3, J6.1, J6.3, J6.5, J6.7, J9.1, U6A301.1 (GND1), U6A301.10 (GND2), U6A301.11 (GND3), U6A301.20 (GND4), U10B301.1 (GND1), U10B301.10 (GND2), U10B301.11 (GND3), U10B301.20 (GND4), U14A301.1 (GND1), U14A301.10 (GND2), U14A301.11 (GND3), U14A301.20 (GND4); also elsewhere on the board
FHDSEL: J4.16, J6.12, U10B301.12 (F8B)
FMSE.X1: J5.5, U14A301.13 (F7B)
FMSE.X2: J5.4, U14A301.14 (F6B)
FM_HSK: J2.7, U6A301.19 (F1B)
FM_RXDM: J2.9, U6A301.16 (F4B)
FM_RXDP: J2.8, U6A301.18 (F2B)
FM_TXDM: J2.5, U6A301.15 (F5B)
FM_TXDP: J2.4, U6A301.17 (F3B)
FPHI0: J4.11, J6.2, U10B301.17 (F3B)
FPHI1: J4.12, J6.4, U10B301.16 (F4B)
FPHI2: J4.13, J6.6, U10B301.15 (F5B)
FPHI3: J4.14, J6.8, U10B301.14 (F6B)
FPWM: J4.10, J6.20, U14A301.16 (F4B)
FP_HSK: J3.7, U6A301.14 (F6B)
FP_RXDM: J3.9, U10B301.19 (F1B)
FP_RXDP: J3.8, U6A301.13 (F7B)
FP_TXDM: J3.5, U10B301.18 (F2B)
FP_TXDP: J3.4, U6A301.12 (F8B)
FRD: J4.18, J6.16, U14A301.18 (F2B)
FWR: J4.19, J6.18, U14A301.17 (F3B)
F/ENBL1: J6.14, U14A301.19 (F1B)
F/ENBL2: J4.17, U14A301.15 (F5B)
F/MSE.SW: J5.7, U14A301.12 (F8B)
F/WREQ: J4.15, J6.10, U10B301.13 (F7B)
GND: C19.2, U5C301.7 (IC-), U5C301.8 (GND), U5C301.9 (ID-), U5C301.12 (/E2), U6C301.4 (Mode), U6C301.5 (GND), U7B301.5 (2IN+), U13B301.1, U13B301.7 (VSS); also elsewhere on the board
HDSEL: U10B301.9 (F8A); also elsewhere on the board
HSKA: U5C301.5 (OC); also elsewhere on the board
HSKB: U5C301.11 (OD); also elsewhere on the board
KBD.ACLK: FB4.1, R22.2; also elsewhere on the board
KBD.DATA: FB5.1; also elsewhere on the board
MSE.X1: R25.2, U14A301.8 (F7A); also elsewhere on the board
MSE.X2: U14A301.7 (F6A); also elsewhere on the board
MSE.Y1: FB2.1, R24.2; also elsewhere on the board
MSE.Y2: FB1.1; also elsewhere on the board
M_HSK: U5C301.6 (IC+), U6A301.2 (F1A)
M_RXDM: U5C301.1 (IA-), U6A301.5 (F4A)
M_RXDP: U5C301.2 (IA+), U6A301.3 (F2A)
M_TXDM: U6A301.6 (F5A), U6C301.11 (OC)
M_TXDP: U6A301.4 (F3A), U6C301.10 (OD)
unnamed: C10.1, C11.2, C12.2, R15.1, U7B301.6 (2IN-)
unnamed: C10.2, Q2.3 (C), Q3.1 (E), R7.2, R15.2, R29.2
unnamed: C11.1, C12.1, R13.2, U13B301.3, U13B301.9, U13B301.10
unnamed: C18.1, R14.2, R18.2
unnamed: C18.2, R12.1, R13.1, R16.1, R17.1, U7B301.1 (1OUT), U7B301.2 (1IN-)
unnamed: C19.1, R14.1, U7B301.3 (1IN+)
unnamed: J5.8, R26.2
unnamed: J5.9, R27.2
unnamed: J9.2, R37.2
unnamed: J9.3, R38.2
unnamed: Q2.2 (B), Q3.2 (B), R29.1, U7B301.7 (2OUT)
unnamed: R12.2, U13B301.11
unnamed: R16.2, U13B301.4
unnamed: R17.2, U13B301.8
unnamed: R18.1, R19.2, U13B301.2
PHI0: U10B301.4 (F3A); also elsewhere on the board
PHI1: U10B301.5 (F4A); also elsewhere on the board
PHI2: U10B301.6 (F5A); also elsewhere on the board
PHI3: U10B301.7 (F6A); also elsewhere on the board
PWM: U14A301.5 (F4A); also elsewhere on the board
P_HSK: U5C301.10 (ID+), U6A301.7 (F6A)
P_RXDM: U5C301.15 (IB-), U10B301.2 (F1A)
P_RXDP: U5C301.14 (IB+), U6A301.8 (F7A)
P_TXDM: U6C301.14 (OB), U10B301.3 (F2A)
P_TXDP: U6A301.9 (F8A), U6C301.15 (OA)
RD: U14A301.3 (F2A); also elsewhere on the board
RXDA: U5C301.3 (OA); also elsewhere on the board
RXDB: U5C301.13 (OB); also elsewhere on the board
S5: R10.2, U5C301.4 (E1); also elsewhere on the board
SPKR: R1.2; also elsewhere on the board
SV0: U13B301.12; also elsewhere on the board
SV1: U13B301.6; also elsewhere on the board
SV2: U13B301.5; also elsewhere on the board
TXDA: U6C301.2 (IA); also elsewhere on the board
TXDB: U6C301.7 (ID); also elsewhere on the board
WR: U14A301.4 (F3A); also elsewhere on the board
/ENBL1: U14A301.2 (F1A); also elsewhere on the board
/ENBL2: U14A301.6 (F5A); also elsewhere on the board
/MSE.SW: U14A301.9 (F8A); also elsewhere on the board
/OFBUFA: U6C301.3 (IB); also elsewhere on the board
/OFBUFB: U6C301.6 (IC); also elsewhere on the board
/SND: U13B301.13; also elsewhere on the board
/WREQ: U10B301.8 (F7A); also elsewhere on the board

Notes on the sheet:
Note: FB are on the schematic as 27-ohm resistors.
Floppy - Ext/Int
Modem
Keyboard Interface
Printer
NOTE: Schematic indicates RJ-11
Glitch filters are on the side of the schematic.
Sound Generator
NOTE: External floppy connector J4 is a custom-shell DB19F (10-over-9). TE/Tyco/AMP #745971-1 or EDC 111468-2
EMI Deglitch Packs
Mouse

Board: 4 copper layers, 186 parts (0 on the bottom side), 262 nets, no tracks yet.

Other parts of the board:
G001, G002: LOGO

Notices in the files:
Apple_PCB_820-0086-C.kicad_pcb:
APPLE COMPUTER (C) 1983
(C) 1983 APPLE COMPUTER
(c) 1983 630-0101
